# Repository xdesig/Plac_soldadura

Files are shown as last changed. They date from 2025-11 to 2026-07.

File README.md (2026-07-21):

#  Plataforma de Soldadura (Control de Temperatura)

> [!NOTE]
> Documentation in Galego 
> [traductor](https://tradutorgaio.xunta.gal/TradutorPublico/traducir/index)

Este repositorio conten o deseno de hardware, esquema e firmware para o desenvolvemento dun **controlador termico intelixente** aplicado a unha placa calefactora de 230Vac. O sistema esta desenado para labores de soldadura e desoldadura de componentes SMD/THD en proxectos persoais, educativos e experimentais.

---

## Versions do Proxecto

O repositorio esta dividido en duas variantes segundo o microcontrolador utilizado:

### 1. [Plataforma_sold_ATmega328p](./Plataforma_sold_ATmega328p)
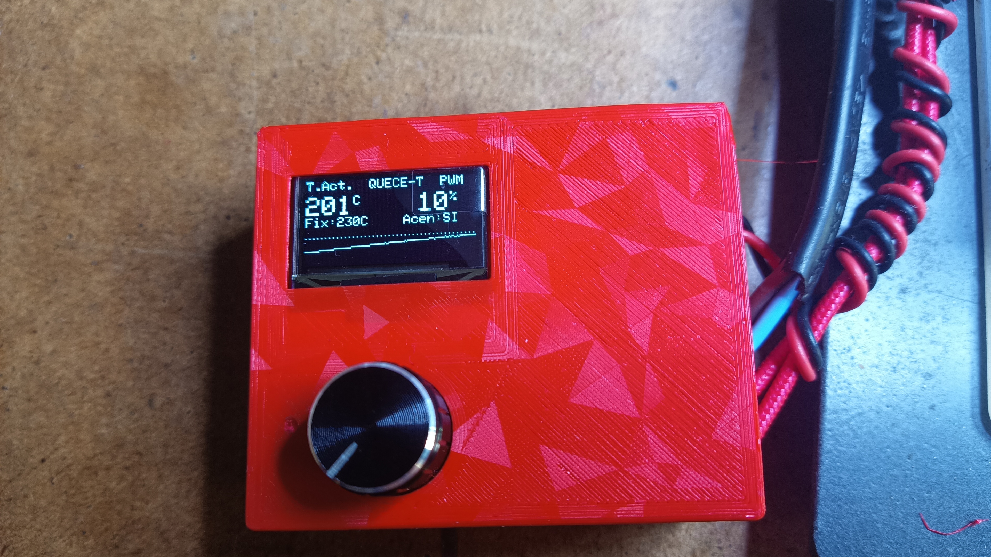
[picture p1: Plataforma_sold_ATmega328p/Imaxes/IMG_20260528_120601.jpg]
ATmega328P Version


- **Microcontrolador:** ATmega328P-AU (TQFP-32).
- **Descricion:** Version mais lixeira e eficiente baseada na arquitectura clasica de Arduino. Demostra que non e preciso usar un potente ESP32 para realizar este traballo.
**Caracteristicas:** Control de potencia, visualizacion en pantalla OLED 128x64 (SSD1306) e illamento galvanico.

**[Ver documentacion e BOM do ATmega328P](./Plataforma_sold_ATmega328p)**

---

### 2. [Plataforma_sold_ESP32-C3](./Plataforma_sold_ESP32-C3)
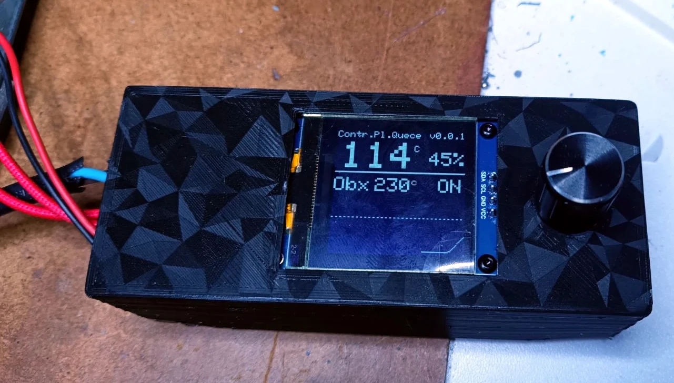
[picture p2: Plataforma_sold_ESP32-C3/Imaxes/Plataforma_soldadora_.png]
ESP32-C3 Version


**Microcontrolador:** ESP32-C3 SuperMini (RISC-V).
**Descricion:** Version baseada no chip ESP32-C3, aproveitando a sua maior velocidade de procesamento e conectividade.
**Caracteristicas:** Interface OLED I2C, control mediante encoder rotatorio e procesamento mais rapido da curva de temperatura.

**[Ver documentacion e BOM do ESP32-C3](./Plataforma_sold_ESP32-C3)**

---

##  Caracteristicas Xerais

Ambas versions comparten a seguinte arquitectura e funcionalidade basica:

- **Control Termico:** Axuste preciso da temperatura e control de potencia do elemento calefactor.
- **Seguridade:** Deteccion de fallos no termistor e corte de emerxencia por sobrequecemento (300 C).
- **Aisllamento:** Illamento galvanico mediante micro-fonte de alimentacion conmutada integrada na PCB.
- **Etapa de Potencia:** Control de carga AC a 230Vac mediante SSR / Triac (BTA06-400B e optoacoplador MOC3041).
- **Interface:** Pantalla OLED SSD1306 (128x64 px) e selector mediante encoder rotatorio e pulsador.

---

## Estrutura do Repositorio

* `Plataforma_sold_ATmega328p/`: Proxecto, PCB e BOM para ATmega328P
* `Plataforma_sold_ESP32-C3/`: Proxecto, PCB e BOM para ESP32-C3
* `README.md`: Descricion xeral do repositorio

---

Saúdos.

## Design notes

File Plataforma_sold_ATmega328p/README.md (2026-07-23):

# Controlador de placa para soldar Con ATmega328p


> [!NOTE]
> Documentation in Galego 
> [traductor](https://tradutorgaio.xunta.gal/TradutorPublico/traducir/index)

Tr&aacute;tase dun **controlador t&eacute;rmico intelixente** de placa calefactora 230Vac para soldar/desoldar, dese&ntilde;ado para uso persoal, educativo e experimental. Baseado en ATmega328, non &eacute; preciso usar un potente ESP32 para realizar este traballo, e permite:

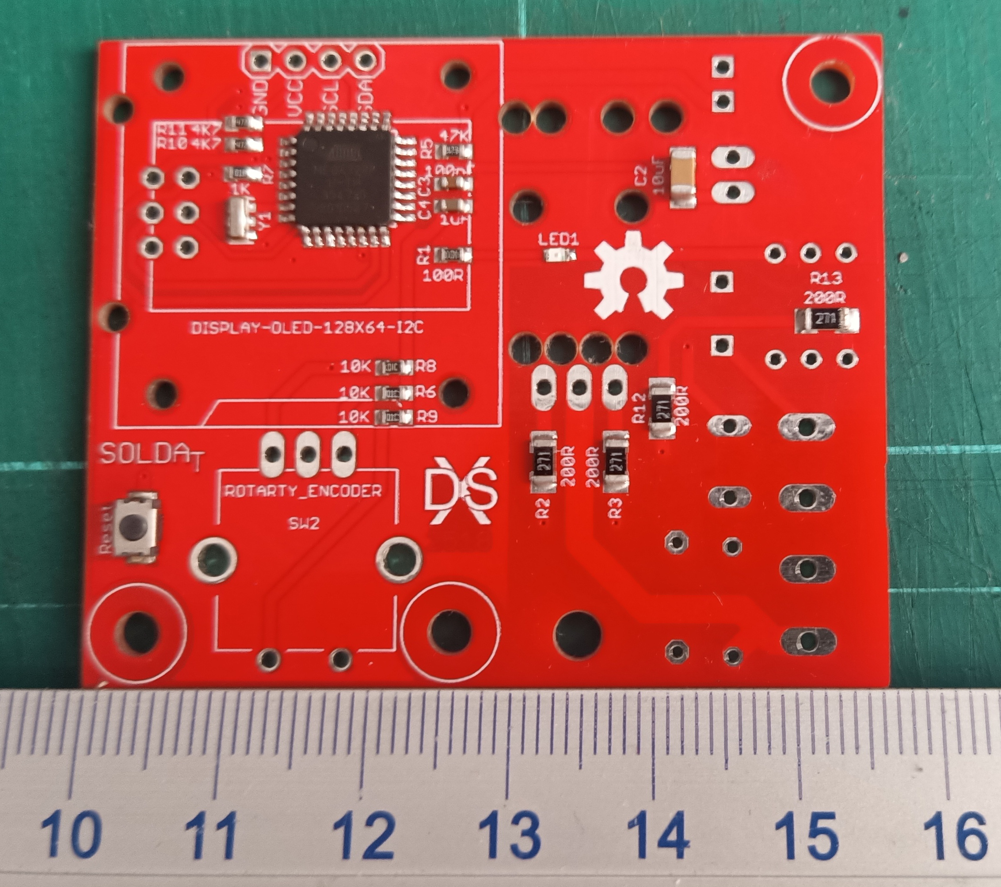
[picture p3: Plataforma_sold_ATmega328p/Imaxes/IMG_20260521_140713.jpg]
 
 
- Axuste preciso da temperatura (ata 300&deg;C).
- Control "PID" simple e estable.
- Detecci&oacute;n de fallos do termistor.
- Gr&aacute;fico en tempo real da temperatura.
- Indicador ON/OFF e potencia aplicada ao calefactor na pantalla.
- Corte de emerxencia por sobrequecemento (300&deg;C).
- Illamento galv&aacute;nico (micro-fonte de alimentaci&oacute;n conmutada).
- Control mediante SSR (Triac) a 230Vac.

<br>
---

## [Versi&oacute;n 00]

## Listado de Compoñentes (BOM)

|Cant | Valor | Dispositivo | Parte | Descrición |
|-----|---|---|---|---|
| **1** | 100R | R0603 | `R1` | Resistor |
| **1** | 100nF | C0603 | `C3` | Capacitor |
| **3** | 10K | R0603 | `R6`, `R8`, `R9` | Resistor |
| **1** | 10nF / 400V | C075-042X103 | `C1` | Capacitor (400V) |
| **1** | 10uF | C1206 | `C2` | Capacitor |
| **1** | 1K | R0603 | `R7` | Resistor |
| **1** | 1uF | C0603 | `C4` | Capacitor |
| **4** | 200R | R1206 | `R2`, `R3`, `R12`, `R13` | Resistor |
| **1** | 22-05-7028-02 | 7395-02 | `J1` | Connector |
| **1** | 39R | 0204/7 | `R4` | Resistor |
| **1** | 47K | R0603 | `R5` | Resistor |
| **2** | 4K7 | R0603 | `R10`, `R11` | Resistor |
| **1** | ATMEGA328P-AU | TQFP-32 | `IC3` | 8-bit Microcontrolador 32KB Flash |
| **1** | B3U-1000P | SMD_157SW | `S6` | Pulsador 4x3mm SMD H2.5mm |
| **1** | BTA06-400B (BT136) | TO-220AB | `T1` | Triac  |
| **1** | CSTCE16M0V53C-R0 | Resonador | `Y1` | Resonador 16MHz SMD |
| **1** | OLED 0.96" I2C | 128x64 Modulo | `OL1` | SSD1306 [GND, VCC, SCL, SDA] |
| **1** | Fusible| TE5 | `F1` | Fusible |
| **1** | MOC3041 | DIL06 / DIP-6 | `OK1` | Optoacoplador, Triac |
| **1** | Rotary Encoder | Rotary Enc Plain | `SW2` | Encoder rotativo pulsador |
| **1** | RPDZN5W6H | Module | `U1` | Modulo Micro fuente A. |

## Deseñado en Entrimo con agarimo.

### Author and license
* Author: XDeSIG [No Twitter, no X]
* License:[ CERN Open Hardware Licence Version 2 - S - Reciprocal][CERN-OHL-W]
* Certification:[ Open Hardware Certification: ES000057][OSHWA]

<br>

<p align="left">
  OSHW Facts
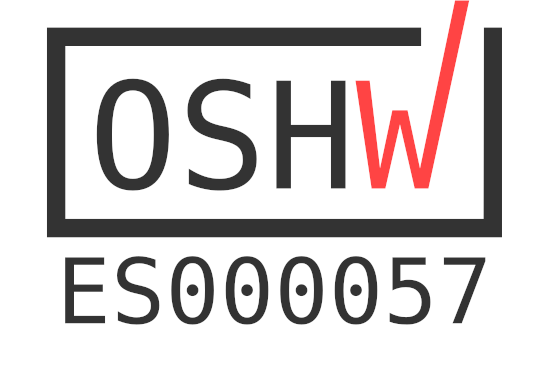
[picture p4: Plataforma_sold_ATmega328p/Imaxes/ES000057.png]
OSHWA Certification
  
</p>

Sa&uacute;dos.
---
[ROTARTY_ENCODER]: https://github.com/xdesig/Plac_soldadura/blob/main/Imaxes/Rotary_encoder.webp
[RPDZN5W6H]: https://github.com/xdesig/Plac_soldadura/blob/main/Imaxes/ac-dc_5V700mA.png
[CERN-OHL-W]: https://ohwr.org/cern_ohl_w_v2.pdf
[OSHWA]: https://certification.oshwa.org/list.html

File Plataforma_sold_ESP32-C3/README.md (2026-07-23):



> [!NOTE]
> Documentation in Galego 
> [traductor](https://tradutorgaio.xunta.gal/TradutorPublico/traducir/index)

Tr&aacute;tase dun **controlador t&eacute;rmico intelixente** de placa calefactora 230Vac para soldar/desoldar, dese&ntilde;ado para uso persoal, educativo e experimental. Esta versi&oacute;n est&aacute; basada no microcontrolador **ESP32-C3 SuperMini**, aproveitando a s&uacute;a alta velocidade e conectividade para a xesti&oacute;n de temperatura e control de potencia.

### Caracter&iacute;sticas principais:
- Axuste preciso da temperatura.
- Control de potencia e ciclo de quecemento.
- Detecci&oacute;n de fallos do sensor de temperatura.
- Visualizaci&oacute;n en pantalla OLED (SSD1306 / I2C).
- Corte de emerxencia por sobrequecemento.
- Illamento galv&aacute;nico (micro-fonte de alimentaci&oacute;n conmutada).
- Control de carga AC mediante triac / SSR.

---

## Listado de Compoñentes (BOM)

| Qty | Value | Device | Package | Parts | Description |
|-----|---|---|---|---|---|
| 1 | | AK500/4-H | AK500/4-H | `X1` | CONNECTOR |
| 1 | | LED3MM | LED3MM | `LED1` | LED 3mm RED |
| 3 | 10K | R-EU_R0603 | R0603 | `R6, R7, R8` | RESISTOR |
| 1 | 10R | R-EU_R0603 | R0603 |`R1` | RESISTOR |
| 1 | 10nF/400V | C-EU075-042X103 | C075-042X103 | `C1` | CAPACITOR |
| 1 | 10uF | C-EUC1206K | C1206K |`C2` | CAPACITOR |
| 1 | 22-27-2021-02| 22-27-2021-02 | 6410-02 | `J1` | CONNECTOR Molex |
| 2 | 390R | R-EU_0204/7 | 0204/7 | `R2, R3` | RESISTOR |
| 1 | 39R | R-EU_0204/7 | 0204/7 | `R4` | RESISTOR |
| 1 | 47K | R-EU_R0603 | R0603 | `R5` | RESISTOR |
| 1 | BTA06400B | BTA06400B | TO220AB | `T1` | Triac BTA |
| 1 | | DISPLAY-OLED-128X128-I2C | DISPLAY-OLED-1,5 pulgadas | `OLED` |SDA, SCL, GND, VCC  |
| 1 | | ESP32-C3_SUPERMINISMD | [ESP32 C3 Supermini]: | `U5` | |
| 1 | | FUS 5A | 8,5x4 | `F1` | Fuse 5A |
| 1 | | MOC3041 | IL410 | `OK1` | OPTO COUPLER |
| 1 | | ROTARTY_ENCODER | [ROTARTY_ENCODER] | `SW2` | Rotary encoder |
| 1 | | RPDZN5W6H | [RPDZN5W6H] | `U1` | AC-DC 5V 700mA |

## Deseñado en Entrimo con agarimo.

### Author and license
* Author: XDeSIG [No Twitter, no X]
* License:[ CERN Open Hardware Licence Version 2 - S - Reciprocal][CERN-OHL-W]
* Certification:[ Open Hardware Certification: ES000055][OSHWA]

<br>

<p align="left">
  OSHW Facts
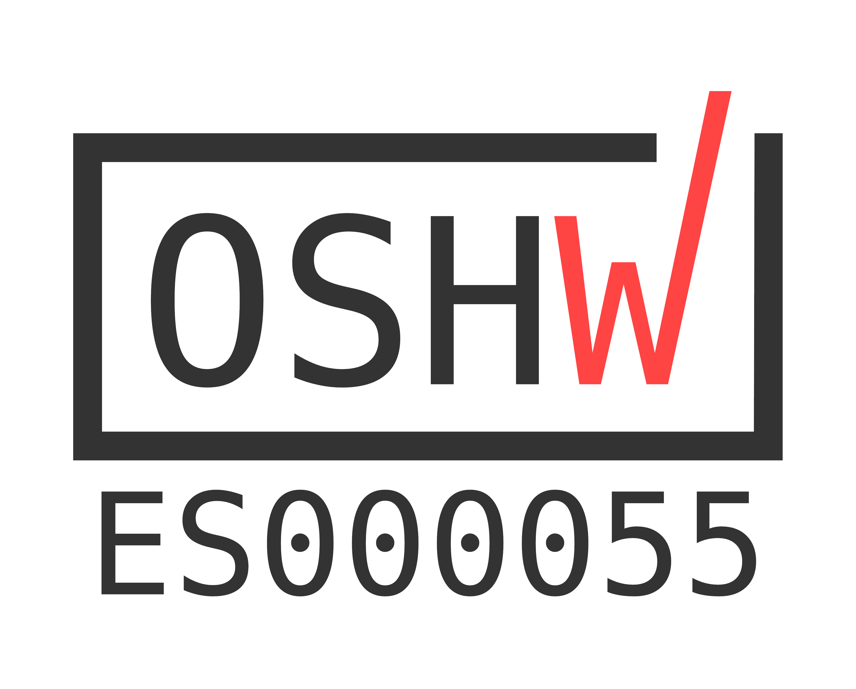
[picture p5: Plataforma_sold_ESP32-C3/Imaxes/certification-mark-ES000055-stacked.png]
OSHWA Certification
  
</p>

---

[ROTARTY_ENCODER]: https://github.com/xdesig/Plac_soldadura/blob/main/Imaxes/Rotary_encoder.webp
[ESP32 C3 Supermini]: https://github.com/xdesig/Plac_soldadura/blob/main/Imaxes/ESP32-C3.webp
[RPDZN5W6H]: https://github.com/xdesig/Plac_soldadura/blob/main/Imaxes/ac-dc_5V700mA.png
[CERN-OHL-W]: https://ohwr.org/cern_ohl_w_v2.pdf
[OSHWA]: https://certification.oshwa.org/list.html

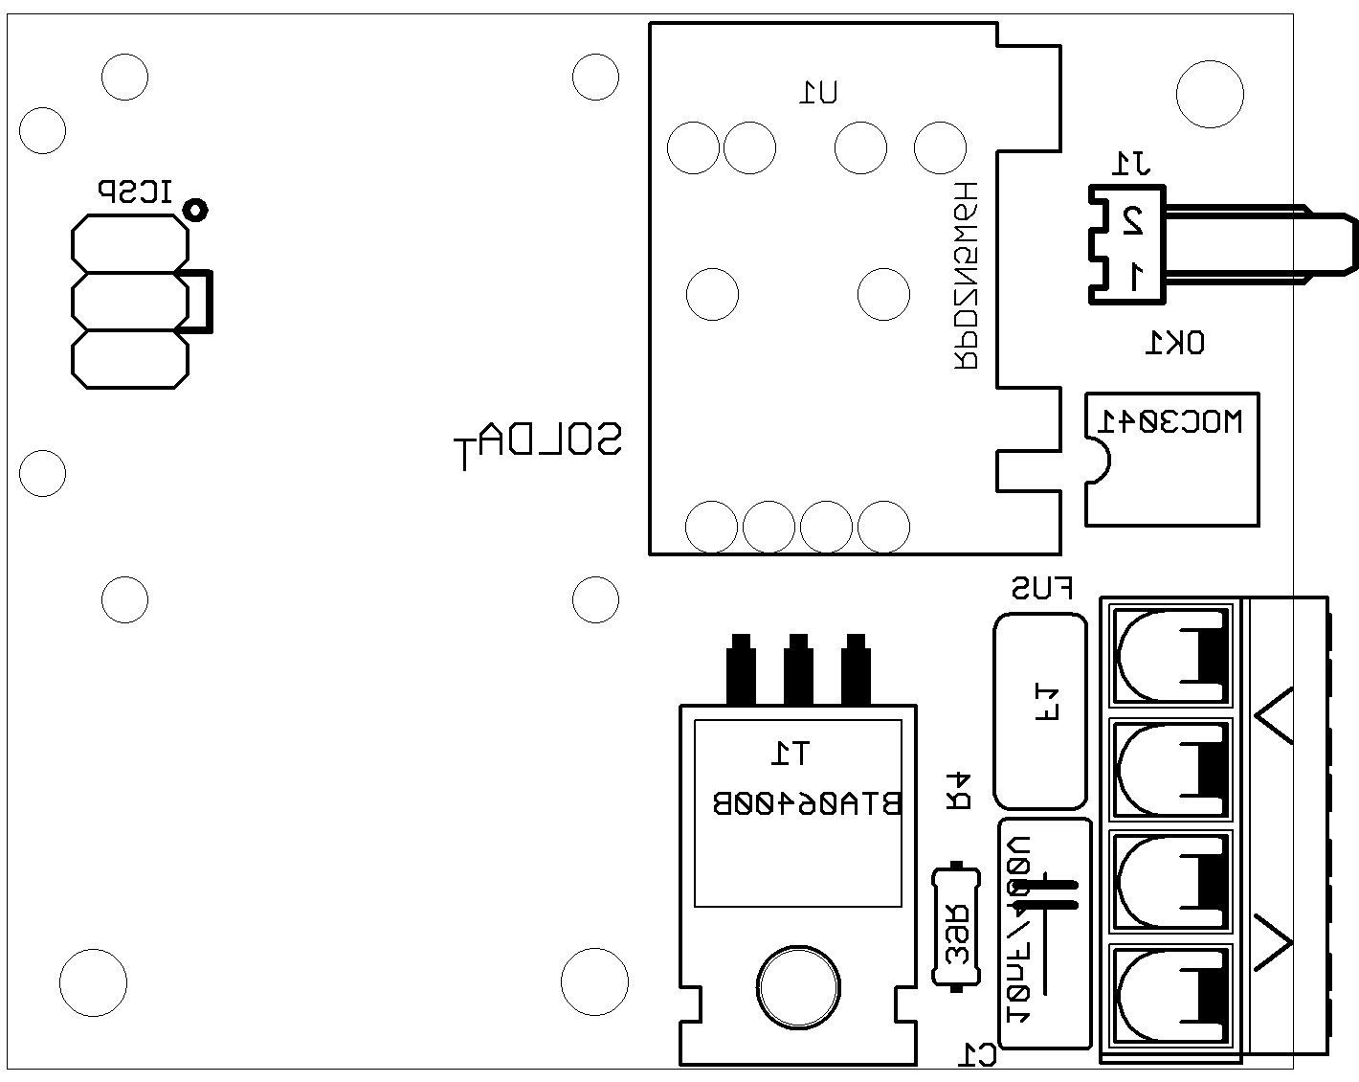
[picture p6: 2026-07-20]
Plataforma_sold_ATmega328p/Electronica/Plato_soldadura_328P_SilkBot.png

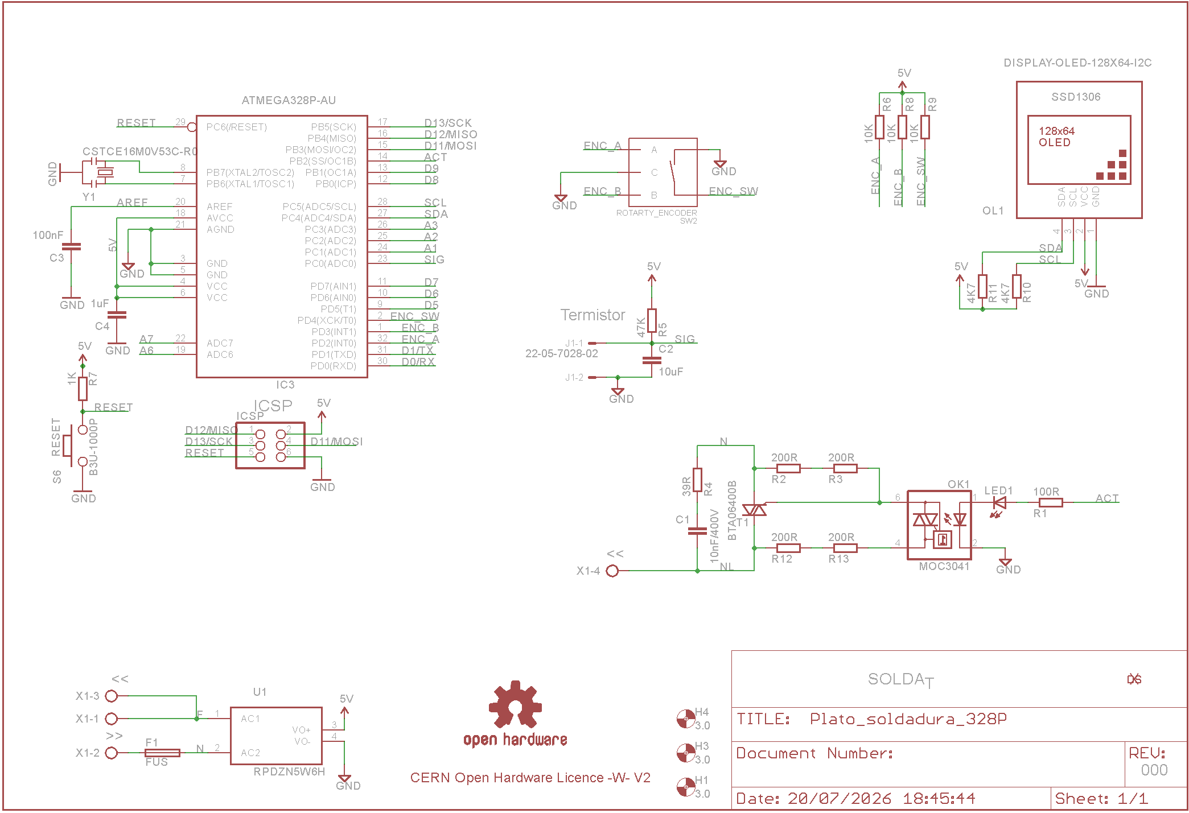
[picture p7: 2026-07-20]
Plataforma_sold_ATmega328p/Electronica/Plato_soldadura_328P_ESQ.png

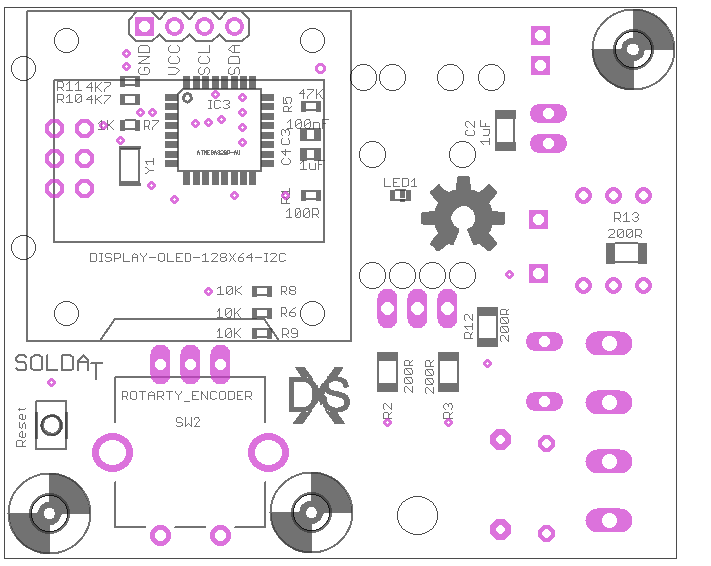
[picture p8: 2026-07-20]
Plataforma_sold_ATmega328p/Electronica/Plato_soldadura_328P_PlacTop.png

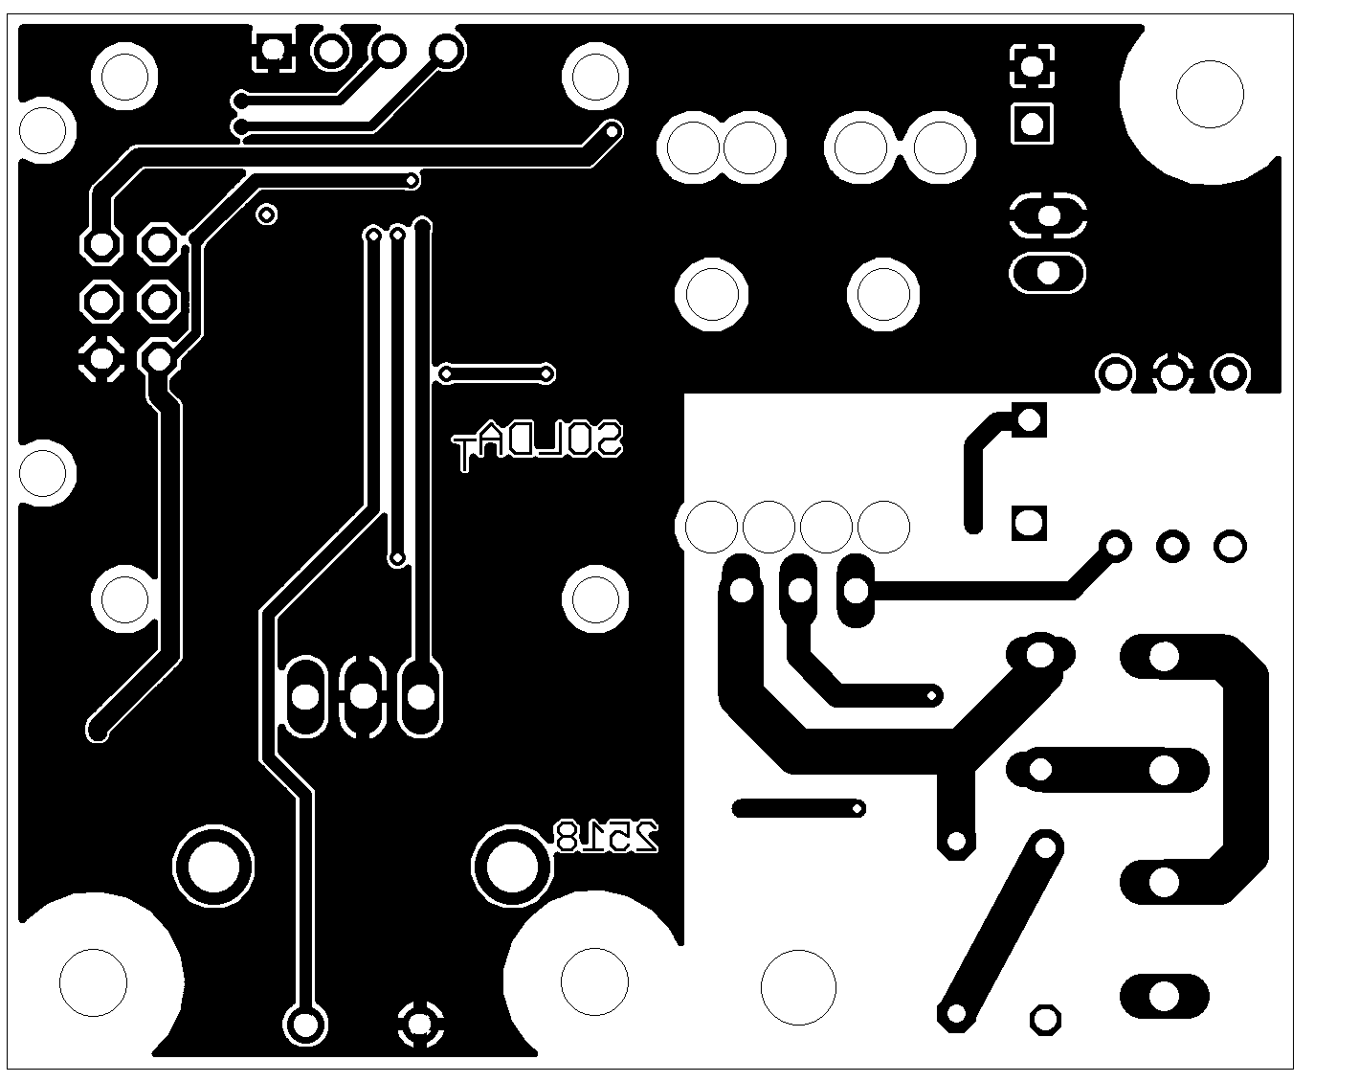
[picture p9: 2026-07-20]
Plataforma_sold_ATmega328p/Electronica/Plato_soldadura_328P_BOT.png

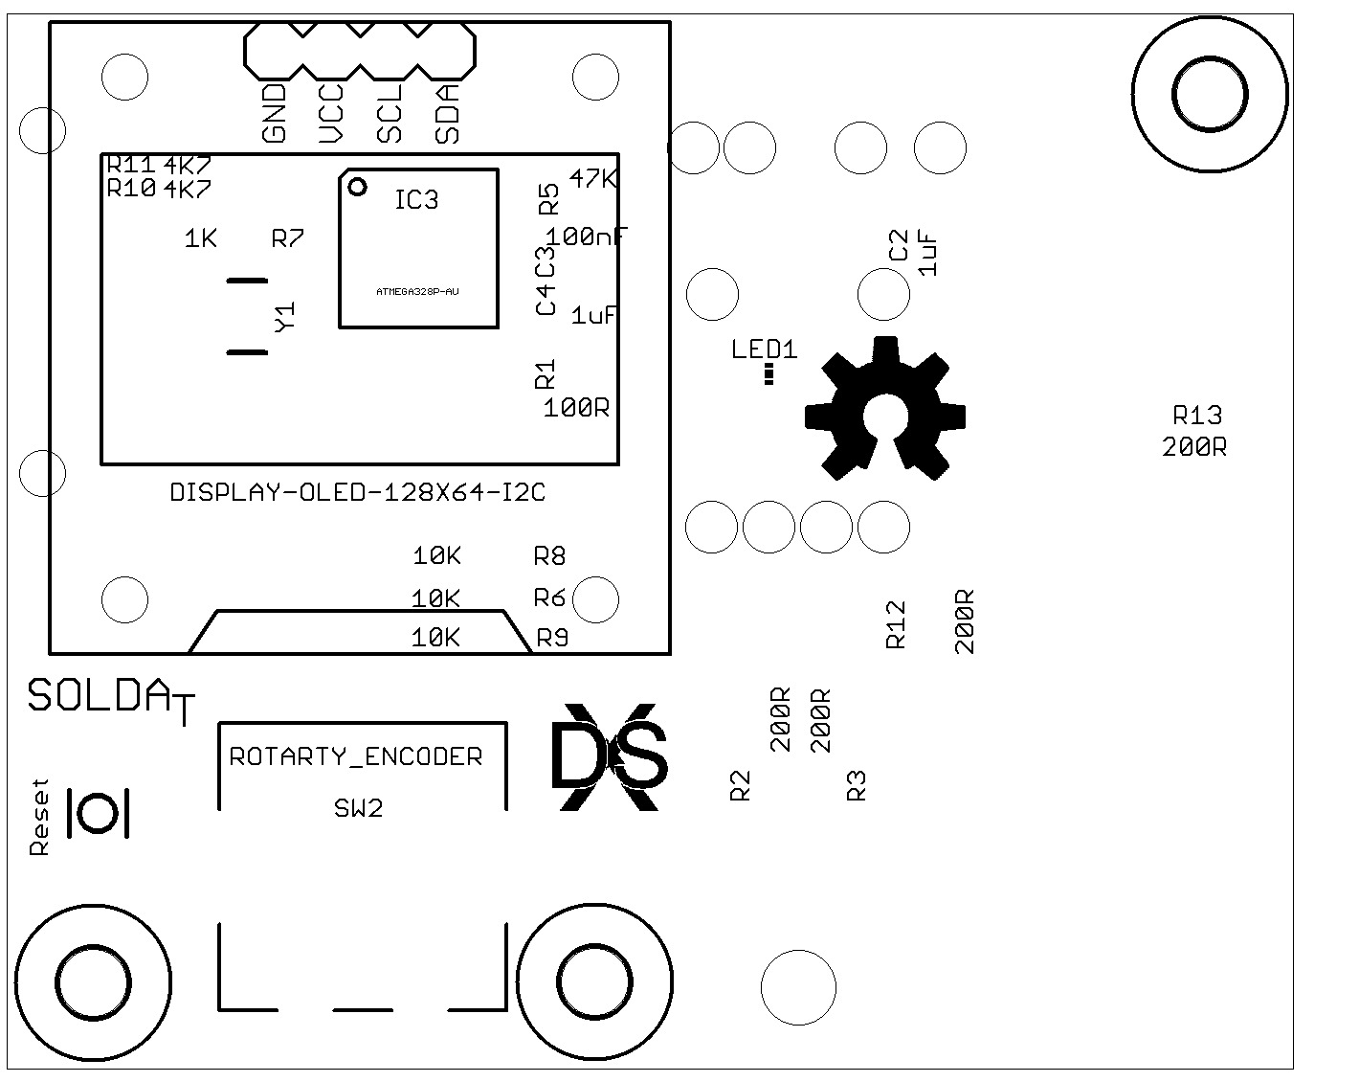
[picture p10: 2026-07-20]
Plataforma_sold_ATmega328p/Electronica/Plato_soldadura_328P_SilkTop.png

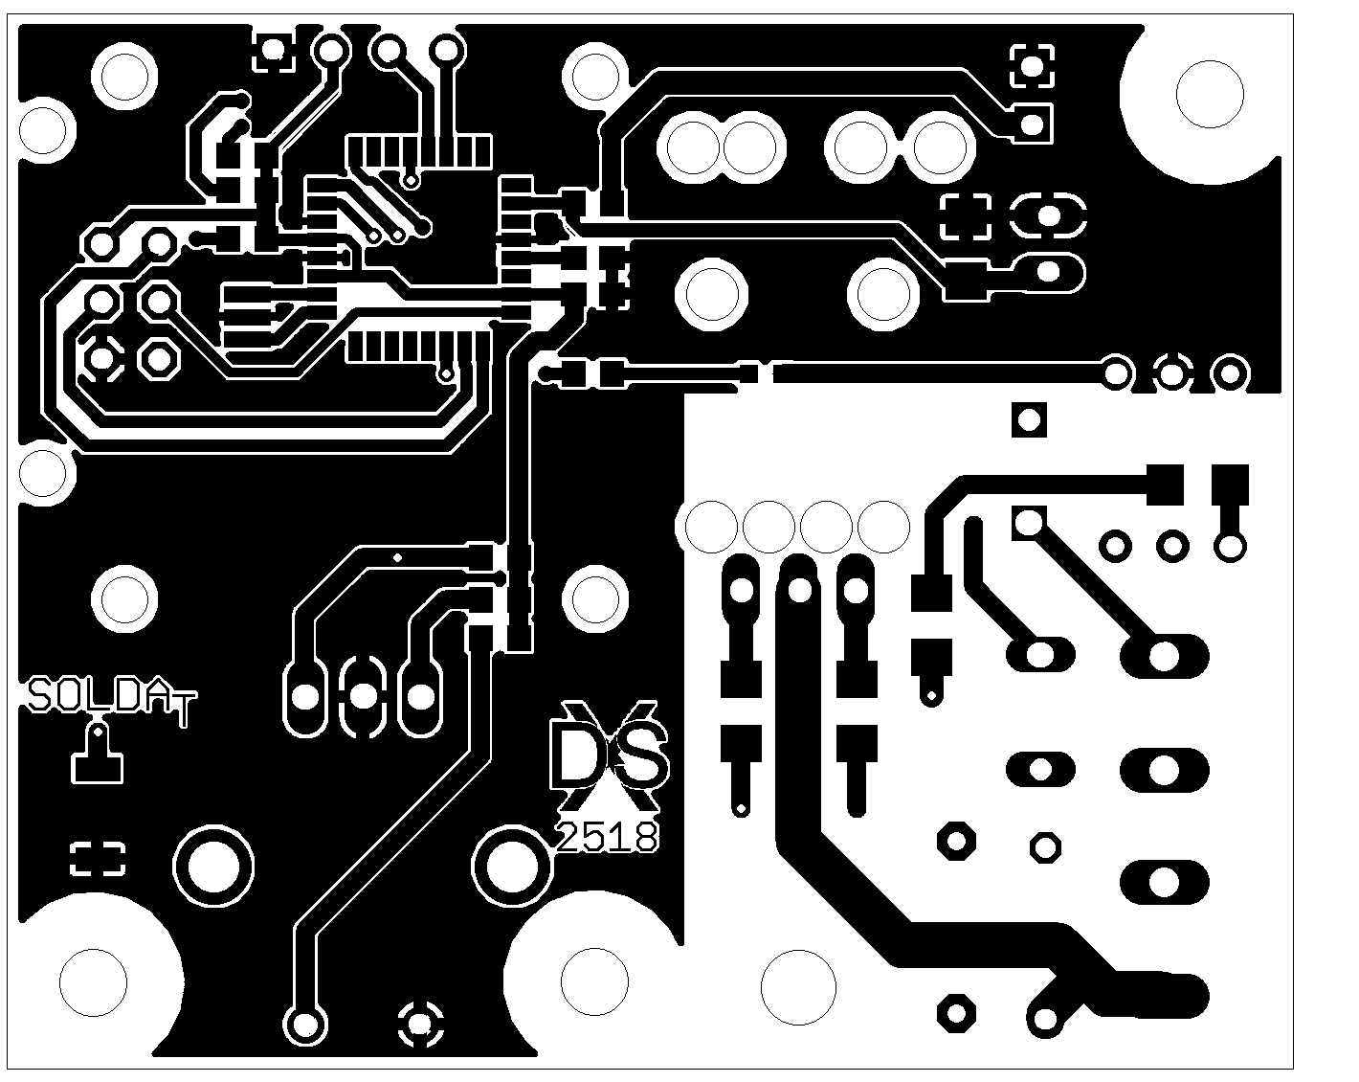
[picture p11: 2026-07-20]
Plataforma_sold_ATmega328p/Electronica/Plato_soldadura_328P_TOP.png

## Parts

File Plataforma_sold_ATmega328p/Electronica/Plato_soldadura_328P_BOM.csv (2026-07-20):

Qty | Value | Device | Package | Parts | Description | CASE | MF | MONTHLY_USAGE | MPN | OC_FARNELL | OC_NEWARK | PART_NUMBER | PRICE | SUPPLIER | TYPE | VALUE
1 |  | 0114_PH254-203DF118A00V | 2X03 | ICSP | 3x2 M V h 8,5 mm p2,54 |  |  | _____ |  |  |  | PH254-203DF118A00V | _____ | _____ | Connettori | ICSP
1 |  | AK500/4-H | AK500/4-H | X1 | CONNECTOR |  |  |  |  | unknown | unknown
1 |  | LEDCHIP-LED0603 | CHIP-LED0603 | LED1 | LED
1 | 100R | R-EU_R0603 | R0603 | R1 | RESISTOR, European symbol
1 | 100nF | C-EUC0603 | C0603 | C3 | CAPACITOR, European symbol
3 | 10K | R-EU_R0603 | R0603 | R6, R8, R9 | RESISTOR, European symbol
1 | 10nF/400V | C-EU075-042X103 | C075-042X103 | C1 | CAPACITOR, European symbol
1 | 10uF | C-EUC1206 | C1206 | C2 | CAPACITOR, European symbol
1 | 1K | R-EU_R0603 | R0603 | R7 | RESISTOR, European symbol
1 | 1uF | C-EUC0603 | C0603 | C4 | CAPACITOR, European symbol
4 | 200R | R-EU_R1206 | R1206 | R2, R3, R12, R13 | RESISTOR, European symbol
1 | 22-05-7028-02 | 22-05-7028-02 | 7395-02 | J1 | CONNECTOR |  |  |  |  | 9731601 | unknown
3 | 3.0 | MOUNT-HOLE3.0 | 3,0 | H1, H3, H4 | MOUNTING HOLE with drill center marker
1 | 39R | R-EU_0204/7 | 0204/7 | R4 | RESISTOR, European symbol
1 | 47K | R-EU_R0603 | R0603 | R5 | RESISTOR, European symbol
2 | 4K7 | R-EU_R0603 | R0603 | R10, R11 | RESISTOR, European symbol
1 | ATMEGA328P-AU | 0265_ATMEGA328P-AU | TQFP32-08 | IC3 | 8-bit Microcontroller with 32KBytes In-System Programmable Flash ATMEGA328P-AU | TQFP32_7x7 |  | _____ |  |  |  | ATMEGA328P-AU | _____ | _____ | Circuito_Integrato | ATMEGA328P-AU
1 | B3U-1000P | 0173_IT-1185AP1C-160G-G_T&R | SMD_157SW | S6 | Pushbutton 4x3 SMD H2,5mm |  |  | _____ |  |  |  | IT-1185AP1C-160G-G_T&R | _____ | _____ | Switches | 157SW
1 | BTA06400B | BT136 | TO220AB | T1 | Triac BT136 series E sensitive gate
1 | CSTCE16M0V53C-R0 | 0011_CSTCE16M0V53-R0 | RESONATOR | Y1 | 16Mhz - SMD |  |  | _____ |  |  |  | CSTCE16M0V53-R0 | _____ | _____ | Cristalli | CSTCE16M0V53-R0
1 | DISPLAY-OLED-128X64-I2C | DISPLAY-OLED-128X64-I2C | DISPLAY-OLED-128X64-I2C | OL1 | 128x64 Dot Matrix OLED Module based on SSD1306 chip
1 | FUS | FUSETE5 | TE5 | F1 | Fuse |  |  |  |  | unknown | unknown
1 | MOC3041 | IL410 | DIL06 | OK1 | SIEMENS OPTO COUPLER |  | VISHAY/TELEFUNKEN |  | IL410 | 1045434 | 58K1715
1 | OSHW-LOGOL | OSHW-LOGOL | ESCORNA_LBRESCORNA_CPU_2_10_SPARKFUN-AESTHETICS_OSHW-LOGO-L | LOGO2 | Open Source Hardware Logo This logo indicates the piece of hardware it is found on incorporates a OSHW license and/or adheres to the definition of open source hardware found here: http://freedomdefined.org/OSHW
1 | ROTARTY_ENCODER | ROTARTY_ENCODER | ROTARY_ENC_PLAIN | SW2 | Simple no LED rotary encoder
1 | RPDZN5W6H | RPDZN5W6H | RPDZN5W6H | U1
1 | XDESIG_XDESIG21 | XDESIG_XDESIG21 | XDESIG_XDESIG | U$8
1 | XDESIG_XDESIG5MM | XDESIG_XDESIG5MM | XDESIG_XDESIG_CU | U$7

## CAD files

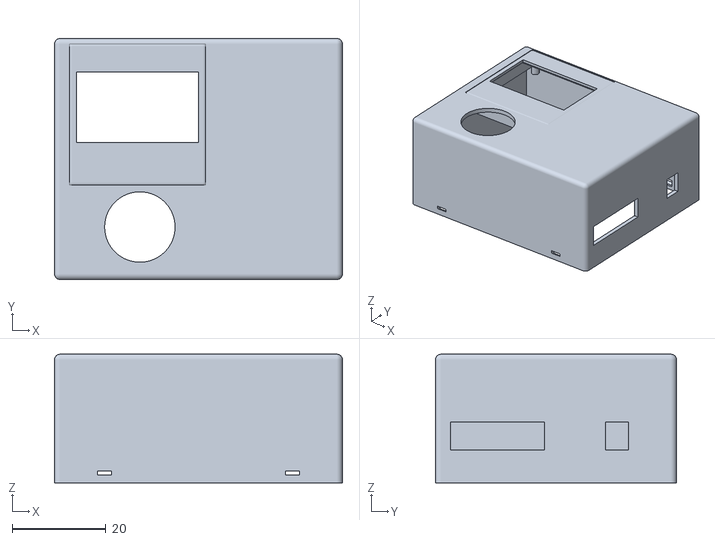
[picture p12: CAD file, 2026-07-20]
Plataforma_sold_ATmega328p/Caixa/Soldadura_328P_Caixa.stl
61.4 x 51.4 x 27.5

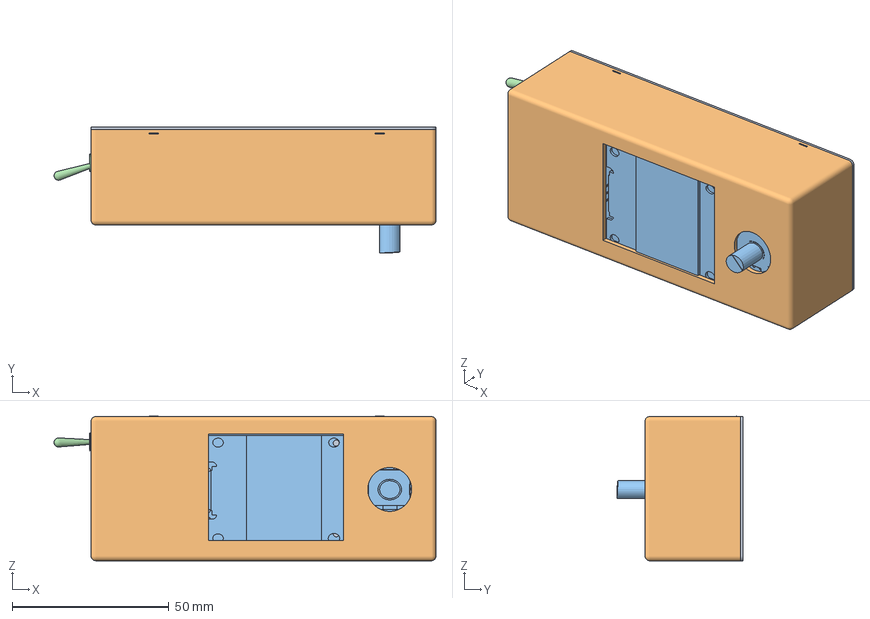
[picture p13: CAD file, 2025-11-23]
Plataforma_sold_ESP32-C3/Caixa/Plataforma_soldadora_caixa_1.FCStd
121.8 x 40.2 x 46.1 mm
Tapa
Caixa
Plataforma_soldadora
255SB

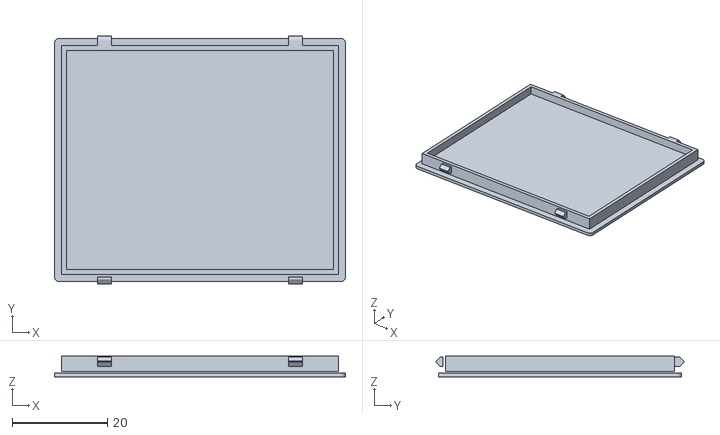
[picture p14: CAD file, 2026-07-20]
Plataforma_sold_ATmega328p/Caixa/Soldadura_328P_Tapa.stl
61.0 x 52.0 x 4.35

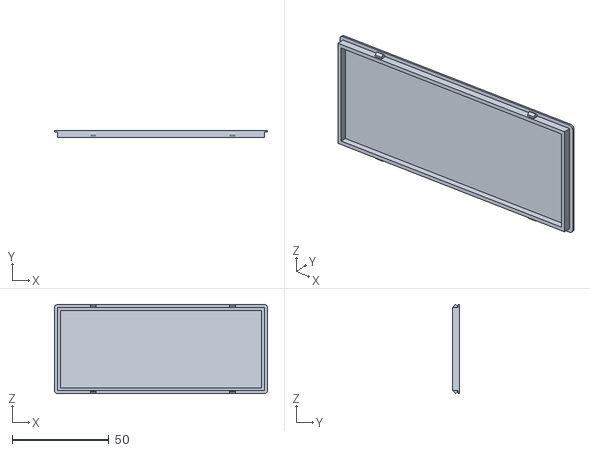
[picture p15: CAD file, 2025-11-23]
Plataforma_sold_ESP32-C3/Caixa/Plataforma_soldadora_tapa_1.stl
110.0 x 3.75 x 46.1

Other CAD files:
Plataforma_sold_ESP32-C3/Caixa/Plataforma_soldadora_caixa_1.stl

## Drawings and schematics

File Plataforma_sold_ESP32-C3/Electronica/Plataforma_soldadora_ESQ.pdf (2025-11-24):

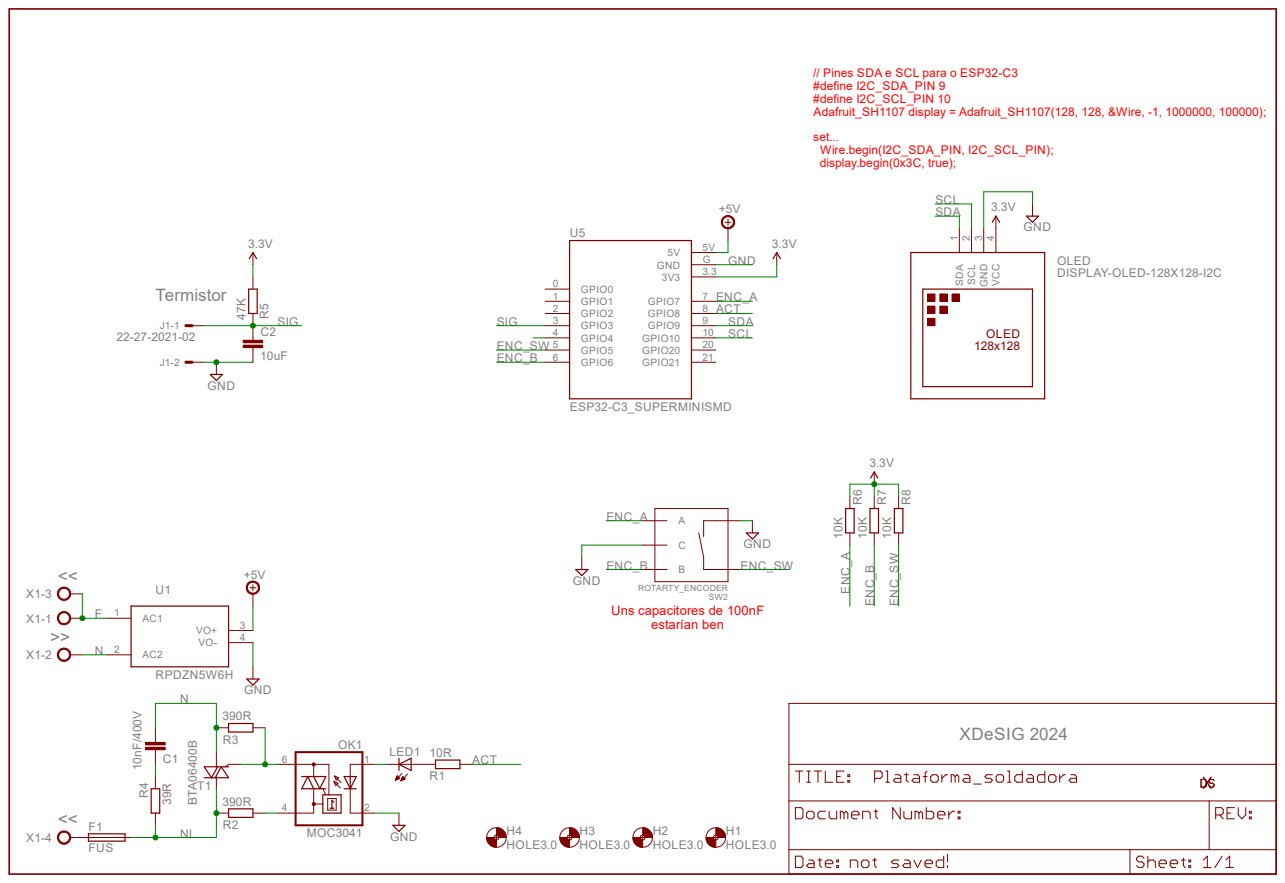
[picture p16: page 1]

// Pines SDA e SCL para o ESP32-C3
#define I2C_SDA_PIN 9
#define I2C_SCL_PIN 10
Adafruit_SH1107 display = Adafruit_SH1107(128, 128, &Wire, -1, 1000000, 100000);
set...
Wire.begin(I2C_SDA_PIN, I2C_SCL_PIN);
display.begin(0x3C, true);

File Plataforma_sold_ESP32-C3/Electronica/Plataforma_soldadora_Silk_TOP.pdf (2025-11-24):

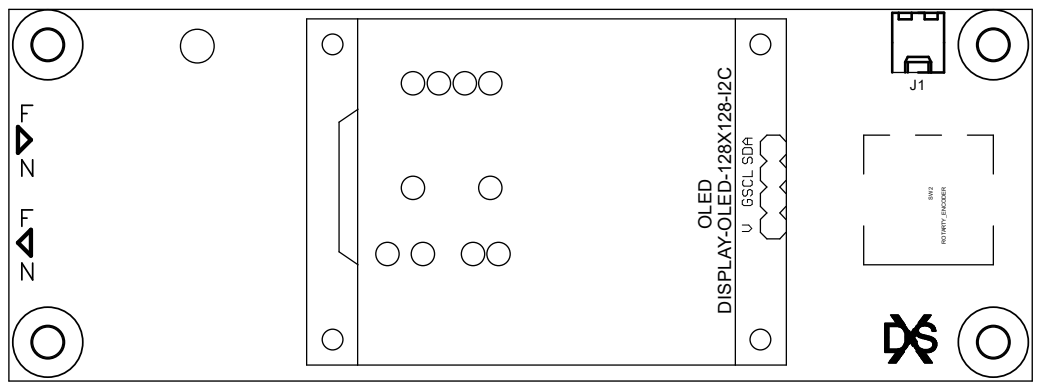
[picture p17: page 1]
SW2 OLED

J1 ROTARTY_ENCODER DISPLAY⁻OLED⁻¹²⁸X¹²⁸⁻I2C

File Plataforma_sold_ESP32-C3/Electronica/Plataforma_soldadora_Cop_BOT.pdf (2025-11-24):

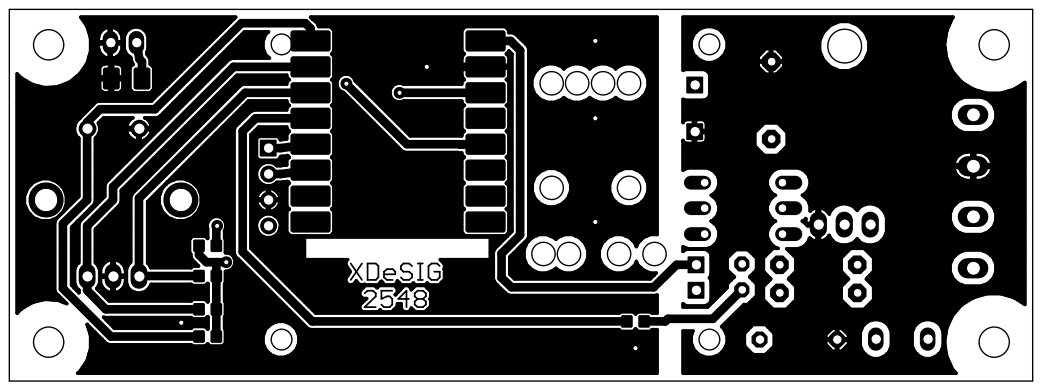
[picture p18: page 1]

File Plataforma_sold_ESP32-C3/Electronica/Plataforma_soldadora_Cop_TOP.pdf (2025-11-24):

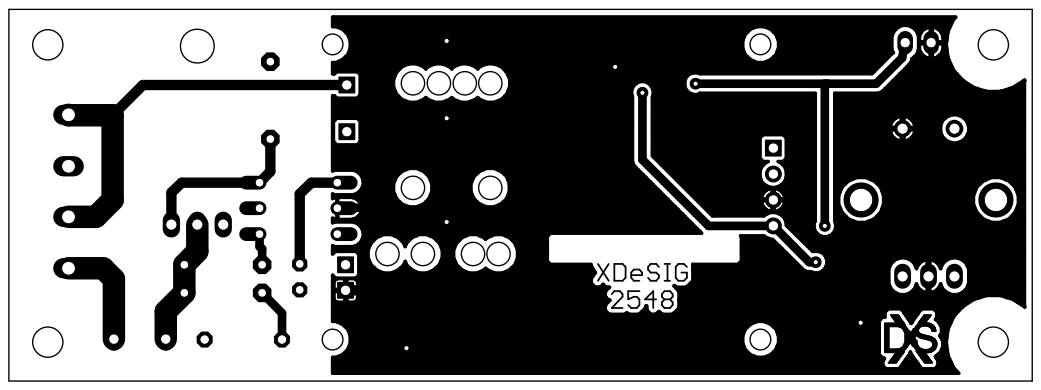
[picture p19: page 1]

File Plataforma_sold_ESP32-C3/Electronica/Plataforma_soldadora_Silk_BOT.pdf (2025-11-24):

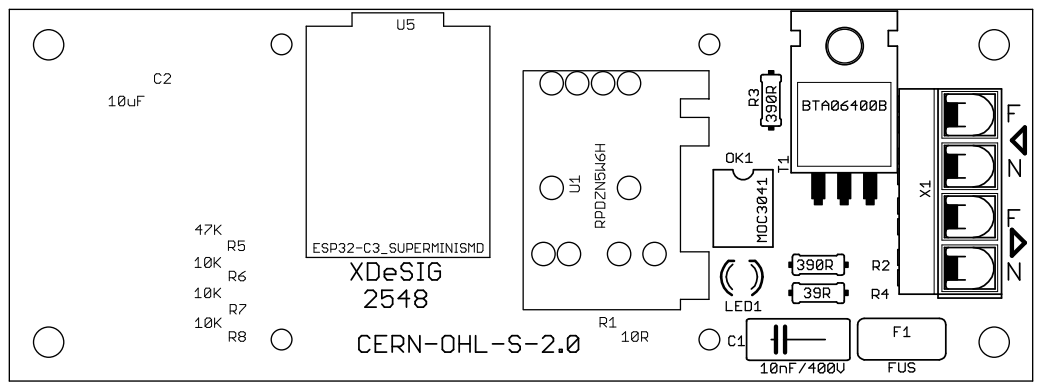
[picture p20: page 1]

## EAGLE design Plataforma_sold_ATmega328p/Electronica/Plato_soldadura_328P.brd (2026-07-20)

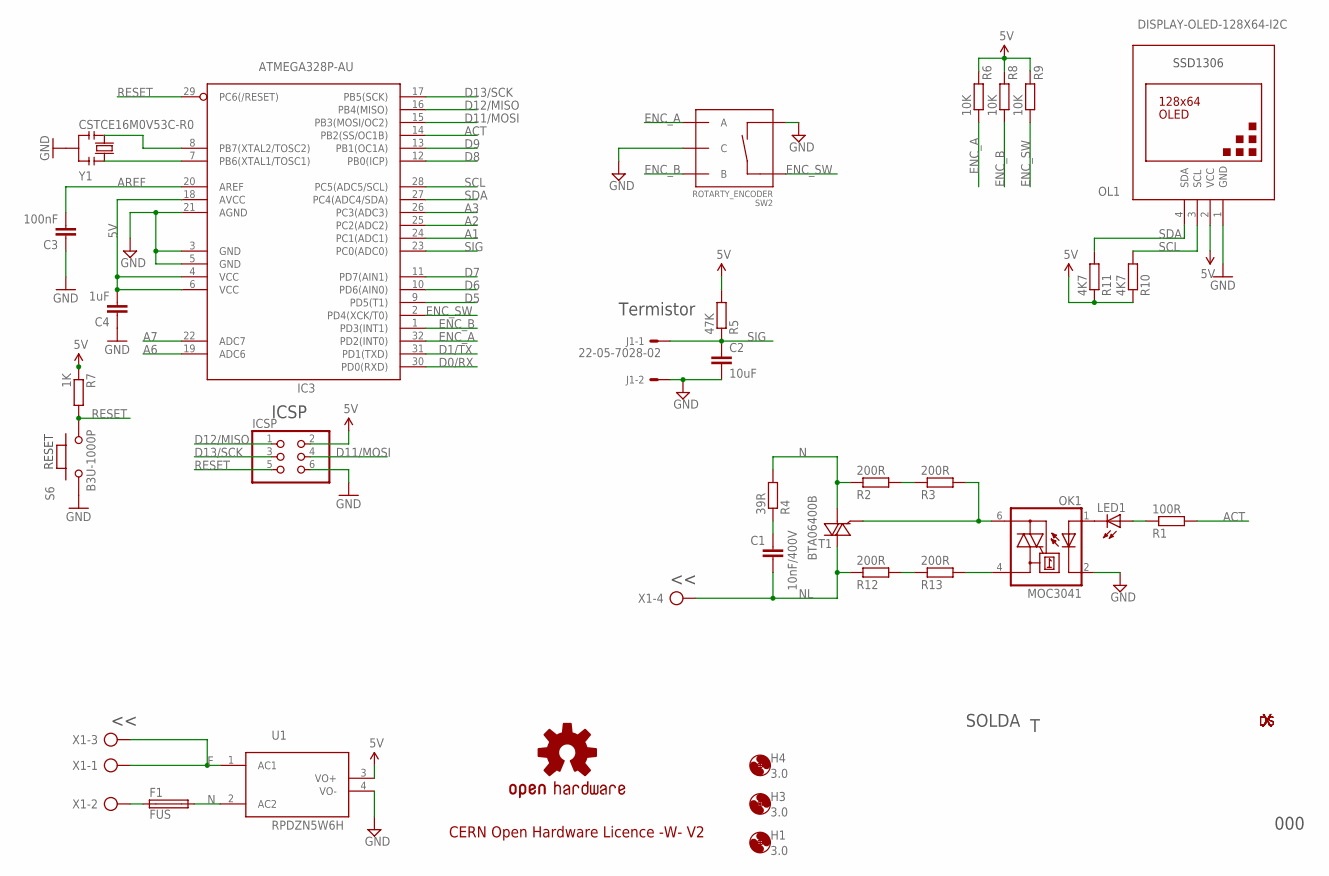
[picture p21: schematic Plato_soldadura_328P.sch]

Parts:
C1: 10nF/400V; C075-042X103
C2: 10uF; C1206
C3: 100nF; C0603
C4: 1uF; C0603
F1: FUS; TE5
H1, H3, H4: 3.0; 3,0
IC3: ATMEGA328P-AU; TQFP32-08
ICSP: 0114_PH254-203DF118A00V; 2X03
J1: 22-05-7028-02; 7395-02
LED1: LEDCHIP-LED0603; CHIP-LED0603
LOGO2: OSHW-LOGOL; ESCORNA_LBRESCORNA_CPU_2_10_SPARKFUN-AESTHETICS_OSHW-LOGO-L
OK1: MOC3041; DIL06
OL1: DISPLAY-OLED-128X64-I2C
R1: 100R; R0603
R2, R3, R12, R13: 200R; R1206
R4: 39R; 0204/7
R5: 47K; R0603
R6, R8, R9: 10K; R0603
R7: 1K; R0603
R10, R11: 4K7; R0603
S6: B3U-1000P; SMD_157SW
SW2: ROTARTY_ENCODER; ROTARY_ENC_PLAIN
T1: BTA06400B; TO220AB
U1: RPDZN5W6H
U$7: XDESIG_XDESIG5MM; XDESIG_XDESIG_CU
U$8: XDESIG_XDESIG21; XDESIG_XDESIG
X1: AK500/4-H
Y1: CSTCE16M0V53C-R0; RESONATOR

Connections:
5V: C4.2, IC3.4 (VCC), IC3.6 (VCC), IC3.18 (AVCC), ICSP.2, OL1.2 (VCC), R5.2, R6.2, R7.1, R8.2, R9.2, R10.1, R11.1, U1.3 (VO+)
A1: IC3.24 (PC1(ADC1))
A2: IC3.25 (PC2(ADC2))
A3: IC3.26 (PC3(ADC3))
A6: IC3.19 (ADC6)
A7: IC3.22 (ADC7)
ACT: IC3.14 (PB2(SS/OC1B)), R1.2
AREF: C3.2, IC3.20 (AREF)
D0/RX: IC3.30 (PD0(RXD))
D1/TX: IC3.31 (PD1(TXD))
D5: IC3.9 (PD5(T1))
D6: IC3.10 (PD6(AIN0))
D7: IC3.11 (PD7(AIN1))
D8: IC3.12 (PB0(ICP))
D9: IC3.13 (PB1(OC1A))
D11/MOSI: IC3.15 (PB3(MOSI/OC2)), ICSP.4
D12/MISO: IC3.16 (PB4(MISO)), ICSP.1
D13/SCK: IC3.17 (PB5(SCK)), ICSP.3
ENC_A: IC3.32 (PD2(INT0)), R6.1, SW2.A
ENC_B: IC3.1 (PD3(INT1)), R8.1, SW2.B
ENC_SW: IC3.2 (PD4(XCK/T0)), R9.1, SW2.SW+
F: U1.1 (AC1), X1.1, X1.3
GND: C2.2, C3.1, C4.1, IC3.3 (GND), IC3.5 (GND), IC3.21 (AGND), ICSP.6, J1.2, OK1.2 (C), OL1.1 (GND), S6.1, SW2.C, SW2.SW-, U1.4 (VO-), Y1.2
N: F1.2, R2.1, R4.2, T1.1 (A1), U1.2 (AC2)
unnamed: OK1.4 (A1), R13.2
unnamed: F1.1, X1.2
unnamed: OK1.6 (A2), R3.2, T1.3 (G)
unnamed: LED1.C, OK1.1 (A)
unnamed: LED1.A, R1.1
unnamed: R2.2, R3.1
unnamed: R12.2, R13.1
unnamed: C1.1, R4.1
unnamed: IC3.7 (PB6(XTAL1/TOSC1)), Y1.1
unnamed: IC3.8 (PB7(XTAL2/TOSC2)), Y1.3
NL: C1.2, R12.1, T1.2 (A2), X1.4
RESET: IC3.29 (PC6(/RESET)), ICSP.5, R7.2, S6.2
SCL: IC3.28 (PC5(ADC5/SCL)), OL1.3 (SCL), R10.2
SDA: IC3.27 (PC4(ADC4/SDA)), OL1.4 (SDA), R11.2
SIG: C2.1, IC3.23 (PC0(ADC0)), J1.1, R5.1

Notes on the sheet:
CERN Open Hardware Licence -W- V2
ICSP
RESET
Termistor
SOLDA
SSD1306
000

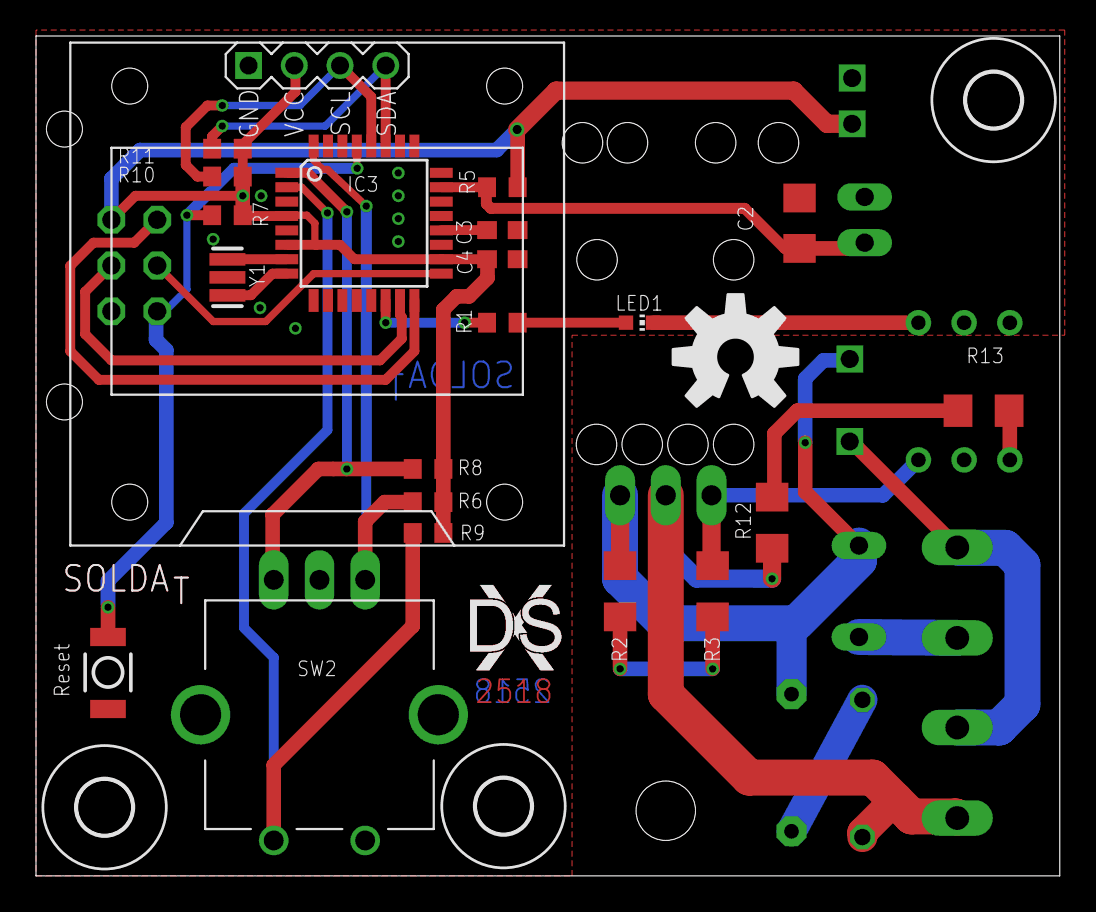
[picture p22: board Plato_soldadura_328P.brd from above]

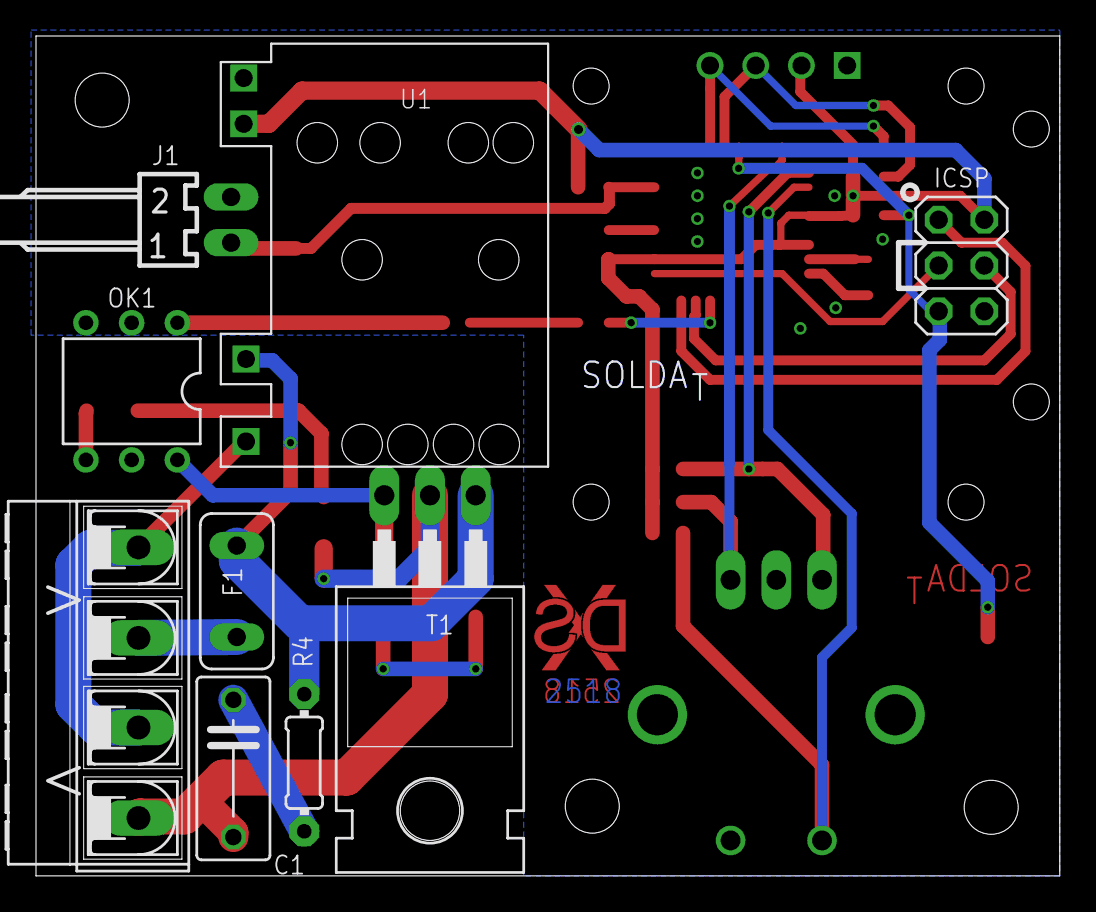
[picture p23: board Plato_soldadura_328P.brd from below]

Board: 2 copper layers, 56.9 x 46.7 mm, 36 parts (9 on the bottom side), 27 nets.

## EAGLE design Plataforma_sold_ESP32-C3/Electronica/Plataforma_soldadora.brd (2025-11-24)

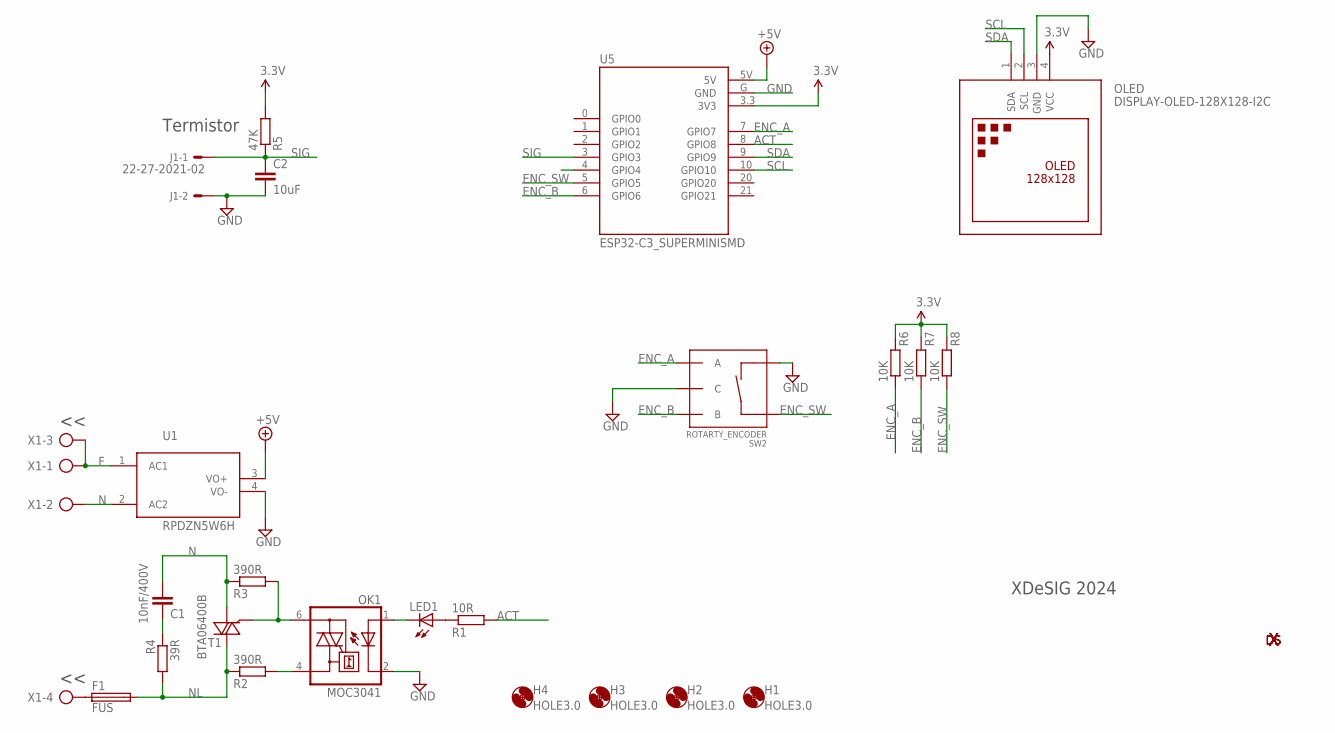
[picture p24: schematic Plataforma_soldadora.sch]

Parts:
C1: 10nF/400V; C075-042X103
C2: 10uF; C1206K
F1: FUS; TE5
H1, H2, H3, H4: HOLE3.0; HOLES_3,0
J1: 22-27-2021-02; 6410-02
LED1: LED3MM
OK1: MOC3041; DIL06
OLED: DISPLAY-OLED-128X128-I2C
R1: 10R; R0603
R2, R3: 390R; 0204/7
R4: 39R; 0204/7
R5: 47K; R0603
R6, R7, R8: 10K; R0603
SW2: ROTARTY_ENCODER; ROTARY_ENC_PLAIN
T1: BTA06400B; TO220AB
U1: RPDZN5W6H
U5: ESP32-C3_SUPERMINISMD; MODULE_ESP-C3_SUPERMINI_SMD
U$2: XDESIG_XDESIG5MM; XDESIG_XDESIG_CU
U$3: XDESIG_XDESIG21; XDESIG_XDESIG
X1: AK500/4-H

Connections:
3.3V: OLED.4 (VCC), R5.2, R6.2, R7.2, R8.2, U5.3.3 (3V3)
+5V: U1.3 (VO+), U5.5V
ACT: R1.2, U5.8 (GPIO8)
ENC_A: R6.1, SW2.A, U5.7 (GPIO7)
ENC_B: R7.1, SW2.B, U5.6 (GPIO6)
ENC_SW: R8.1, SW2.SW+, U5.5 (GPIO5)
F: U1.1 (AC1), X1.1, X1.3
GND: C2.2, J1.2, OK1.2 (C), OLED.3 (GND), SW2.C, SW2.SW-, U1.4 (VO-), U5.G (GND)
N: C1.2, R3.1, T1.1 (A1), U1.2 (AC2), X1.2
unnamed: OK1.4 (A1), R2.2
unnamed: F1.1, X1.4
unnamed: OK1.6 (A2), R3.2, T1.3 (G)
unnamed: LED1.K (C), OK1.1 (A)
unnamed: LED1.A, R1.1
unnamed: C1.1, R4.1
NL: F1.2, R2.1, R4.2, T1.2 (A2)
SCL: OLED.2 (SCL), U5.10 (GPIO10)
SDA: OLED.1 (SDA), U5.9 (GPIO9)
SIG: C2.1, J1.1, R5.1, U5.3 (GPIO3)

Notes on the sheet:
Termistor
XDeSIG 2024

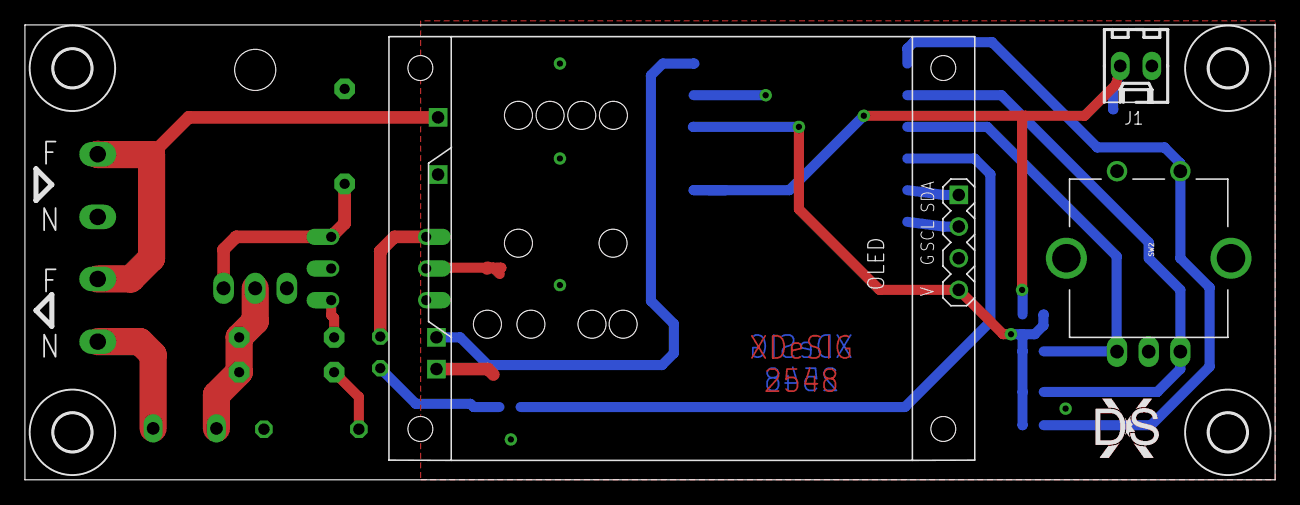
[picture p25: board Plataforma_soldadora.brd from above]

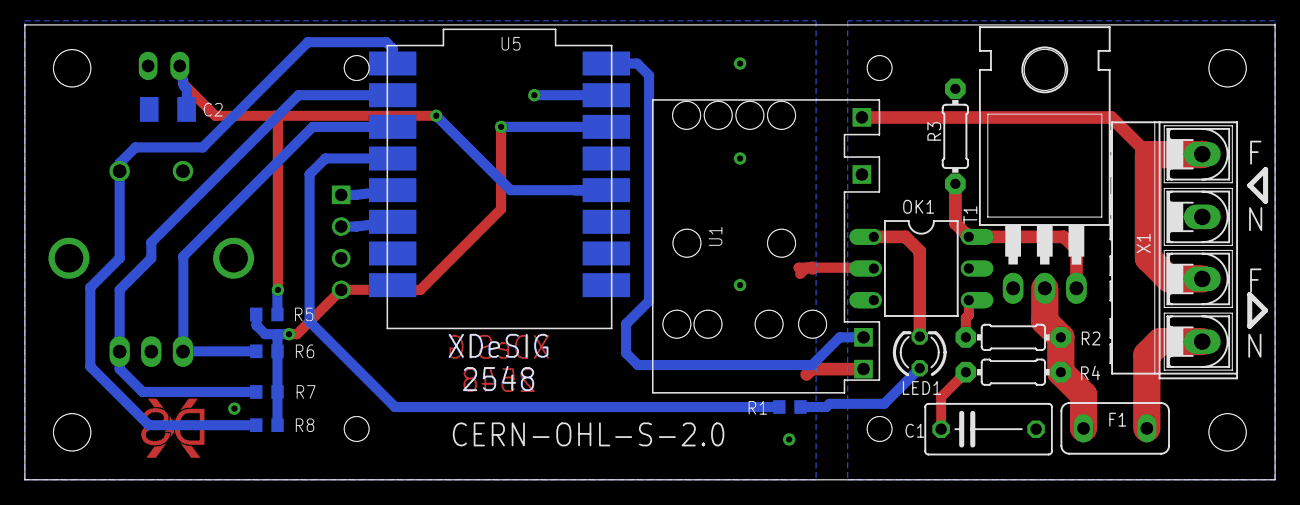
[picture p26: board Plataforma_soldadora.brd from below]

Board: 2 copper layers, 100.3 x 36.5 mm, 26 parts (17 on the bottom side), 19 nets.

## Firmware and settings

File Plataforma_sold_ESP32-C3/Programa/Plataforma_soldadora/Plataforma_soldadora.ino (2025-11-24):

/* CERN Open Hardware Licence -W- V2
 * =============================================================
 * PROXECTO: Controlador Intelixente de Placa Calefactora para soldar/desoldar
 * AUTOR: XDeSIG
 * LICENZA: Código fonte aberto (Open Source)
 * PLATAFORMA: ESP32-C3
 * PANTALLA: OLED SH1107 (128x128)
 * FUNCIONALIDADES:
 *   - Control térmico con termistor NTC 100kΩ
 *   - Axuste de temperatura mediante codificador rotativo
 *   - Controlador P simple estable e seguro
 *   - Gráfico en tempo real da temperatura
 *   - Detección de fallos do sensor (desconexión)
 *   - Corte de emerxencia por sobrecalentamento
 *   - Logo de XDeSIG ao arrancar
 *   - Indicador ON/OFF do calefactor na pantalla principal
 * 
 * Este software é de fonte libre e está deseñado para uso educativo,
 * experimental e persoal. Podes modificar, compartir e mellorar este
 * código libremente, sempre que se recoñeza a autoría orixinal.
 * CERN-OHL-W V2.0
 * 
 * Feito con agarimo en Estrimia
 * =============================================================
 */

#include <Arduino.h>
#include <Wire.h>
#include <Encoder.h>
#include <Adafruit_GFX.h>
#include <Adafruit_SH110X.h>
#include <math.h>

// =============================================================================
// VERSIÓN DO SOFTWARE
// =============================================================================
const char* VERSIÓN_SOFTWARE = "v0.0.1";  // Versión inicial

// =============================================================================
// CONFIGURACIÓN AXUSTABLE POLO USUARIO
// =============================================================================
#define TEMP_MINIMA 20           // Temperatura mínima permitida (°C)
#define TEMP_MAXIMA 300          // Temperatura máxima permitida (°C)
#define PWM_MAX_SAIDA 230        // Potencia máxima do calefactor (0-255)
#define CORTE_EMERXENCIA 301.0f  // Temperatura de corte de seguridade (°C)
#define GANANCIA_KP 1.0f         // Forza de resposta do controlador (P)
#define ALTURA_GRAFICO 64//48        // Altura do gráfico en píxeles
#define ANCHURA_GRAFICO 128      // Anchura do gráfico

// =============================================================================
// DEFINICIÓN DOS PINES DO ESP32-C3
// =============================================================================
#define PIN_SDA_I2C 9
#define PIN_SCL_I2C 10
#define PIN_TERMISTOR 3   // Entrada analóxica do sensor
#define PIN_CALEFACTOR 8  // Saída PWM para o calefactor
#define PIN_COD_ENC_A 6   // Canal A do codificador
#define PIN_COD_ENC_B 7   // Canal B do codificador
#define PIN_COD_SW 5      // Botón do codificador

// =============================================================================
// CONSTANTES FIXAS DO SISTEMA
// =============================================================================
const int PASO_TEMP = 5;
const long ATRASO_ANTIRREbote = 50;
const long INTERVALO_ACTUALIZACION_PANT = 200;
const long INTERVALO_ACTUALIZACION_GRAF = 2500;

// Parámetros do termistor NTC (100kΩ)
const float RESISTENCIA_NOMINAL = 100000.0f;
const float RESISTENCIA_DIVISOR = 32500.0f;
const float BETA_TERMISTOR = 3950.0f;
const float TEMP_NOMINAL = 25.0f;
const float TENSAO_ALIMENTACION = 3.3f;
const float ADC_MAXIMO = 4095.0f;

// =============================================================================
// DECLARACIÓN DO LOGO (definido ao final)
// =============================================================================
extern const unsigned char logo_XDeSIG_128x120[];

// =============================================================================
// VARIABLES GLOBAIS
// =============================================================================
float gananciaKp = GANANCIA_KP;
int temperaturaObxectivo = 230;
float puntoAxuste = temperaturaObxectivo;
float temperaturaActual = 0.0f;
int valorPWM = 0;

bool calefactorActivo = false;
bool controladorActivo = false;

enum EstadoControl { TEMPERATURA_BLOQUEADA,
                     TEMPERATURA_AXUSTE };
EstadoControl estadoActual = TEMPERATURA_AXUSTE;

Adafruit_SH1107 pantalla = Adafruit_SH1107(128, 128, &Wire, -1, 400000);
Encoder codificador(PIN_COD_ENC_A, PIN_COD_ENC_B);

long valorAnteriorCodificador = 0;
unsigned long ultimoPulsoBoton = 0;
bool estadoAnteriorBoton = HIGH;
unsigned long ultimaActualizacionPantalla = 0;
unsigned long ultimaActualizacionGrafico = 0;

float historicoTemperatura[ANCHURA_GRAFICO];
int indiceGrafico = 0;
bool graficoInicializado = false;

// =============================================================================
// FUNCIÓNS
// =============================================================================

float obterTemperatura(int valorADC) {
  if (valorADC <= 0 || valorADC >= ADC_MAXIMO)
    return valorADC <= 0 ? 500.0f : -50.0f;

  float voltaxeSaida = (float)valorADC * (TENSAO_ALIMENTACION / ADC_MAXIMO);
  float resistenciaTermistor = RESISTENCIA_DIVISOR * (voltaxeSaida / (TENSAO_ALIMENTACION - voltaxeSaida));

  float steinhart = log(resistenciaTermistor / RESISTENCIA_NOMINAL) / BETA_TERMISTOR;
  steinhart += 1.0f / (TEMP_NOMINAL + 273.15f);
  steinhart = 1.0f / steinhart - 273.15f;
  return steinhart;
}
// Pantalla de erro
void amosarPantallaErro() {
  pantalla.clearDisplay();
  pantalla.setTextSize(2);
  pantalla.setCursor(20, 20);
  pantalla.print("ERRO de");
  pantalla.setCursor(25, 40);
  pantalla.print("SENSOR!");

  pantalla.setTextSize(1);
  pantalla.setCursor(25, 70);
  pantalla.print("Comproba o");
  pantalla.setCursor(25, 80);
  pantalla.print("termistor.");
  pantalla.display();
}

void actualizarTemperaturaObxectivo(int variacion) {
  temperaturaObxectivo += variacion;
  temperaturaObxectivo = constrain(temperaturaObxectivo, TEMP_MINIMA, TEMP_MAXIMA);
  puntoAxuste = temperaturaObxectivo;
  Serial.print("Temperatura Obxectivo: ");
  Serial.println(temperaturaObxectivo);
}

void xestionarCodificador() {
  long valorActual = codificador.read();
  long variacion = valorActual - valorAnteriorCodificador;

  if (variacion != 0) {
    if (variacion > 0) {
      actualizarTemperaturaObxectivo(PASO_TEMP);
    } else {
      actualizarTemperaturaObxectivo(-PASO_TEMP);
    }
    valorAnteriorCodificador = valorActual;
  }
}

void xestionarBoton() {
  bool estadoActualBoton = digitalRead(PIN_COD_SW);
  unsigned long tempoActual = millis();

  if (estadoActualBoton == LOW && estadoAnteriorBoton == HIGH) {
    if (tempoActual - ultimoPulsoBoton > ATRASO_ANTIRREbote) {
      estadoActual = (estadoActual == TEMPERATURA_AXUSTE) ? TEMPERATURA_BLOQUEADA : TEMPERATURA_AXUSTE;
      controladorActivo = (estadoActual == TEMPERATURA_BLOQUEADA);
      Serial.println(estadoActual == TEMPERATURA_BLOQUEADA ? ">>> ESTADO: BLOQUEADO (CONTROL AUTOMÁTICO)" : ">>> ESTADO: AXUSTE (CONTROL MANUAL)");
      if (estadoActual == TEMPERATURA_AXUSTE) {
        valorAnteriorCodificador = codificador.read();
      }
      ultimoPulsoBoton = tempoActual;
    }
  }
  estadoAnteriorBoton = estadoActualBoton;
}

// Actualiza a pantalla OLED con toda a información
void actualizarPantalla() {
  pantalla.clearDisplay();

  // Título e versión
  pantalla.setTextSize(1);
  pantalla.setCursor(0, 0);
  pantalla.print("Contr.Pl.Quece ");
  pantalla.setCursor(128 - (strlen(VERSIÓN_SOFTWARE) * 6), 0);
  pantalla.print(VERSIÓN_SOFTWARE);

  // Temperatura actual (grande) + estado do calefactor
  pantalla.setTextSize(4);
  pantalla.setCursor(5, 12);
  pantalla.print((int)temperaturaActual);
  pantalla.setTextSize(1);

  // Unidade 'C'
  int lonxTextoTemp = String((int)temperaturaActual).length();
  int posX_C = 5 + (lonxTextoTemp * 24);
  pantalla.setCursor(posX_C, 15);
  pantalla.print("C");

  // Estado do calefactor (ON/OFF) á dereita
  int posX_estado = posX_C + 15;  // 6 píxeles despois do "C"
  pantalla.setTextSize(2);
  pantalla.setCursor(posX_estado, 22);
  int porcentaxe = (int)(valorPWM * 100 / 255);
  pantalla.print(porcentaxe);
  pantalla.print("%");


  // Liña separadora
  pantalla.drawLine(0, 44, 127, 44, SH110X_WHITE);

  // Temperatura obxectivo
  pantalla.setTextSize(2);
  pantalla.setCursor(0, 50);
  pantalla.print("Obx");
  if (estadoActual == TEMPERATURA_AXUSTE) {
    pantalla.setTextColor(SH110X_BLACK, SH110X_WHITE);
  }
  pantalla.setCursor(40, 50);
  pantalla.print(temperaturaObxectivo);
  pantalla.setTextSize(1);
  pantalla.print("c");
  pantalla.setCursor(90, 50);
  if (estadoActual == TEMPERATURA_AXUSTE) {
    pantalla.setTextColor(SH110X_WHITE, SH110X_BLACK);
    pantalla.setTextSize(2);
    pantalla.print("OFF");
  } else {
    pantalla.setTextSize(2);
    pantalla.print(" ON");
  }


  // Debuxa o gráfico de temperatura na parte inferior
  if (graficoInicializado) {
    const int desprazamentoY = 128 - ALTURA_GRAFICO;
    pantalla.fillRect(0, desprazamentoY, ANCHURA_GRAFICO, ALTURA_GRAFICO, SH110X_BLACK);

    const float tempMin = 0.0f;
    const float tempMax = 400.0f;
    const float rangoTemp = tempMax - tempMin;

    // Debuxa a curva de temperatura actual
    for (int x = 0; x < ANCHURA_GRAFICO; x++) {
      int indiceBuffer = (indiceGrafico + x) % ANCHURA_GRAFICO;
      float temp = historicoTemperatura[indiceBuffer];
      if (temp < tempMin) temp = tempMin;
      if (temp > tempMax) temp = tempMax;

      int y = desprazamentoY + (int)(ALTURA_GRAFICO - (temp - tempMin) * ALTURA_GRAFICO / rangoTemp);
      pantalla.drawPixel(x, y, SH110X_WHITE);
    }

    // Debuxa a liña do obxectivo con puntos separados (máis visible)
    if (temperaturaObxectivo >= tempMin && temperaturaObxectivo <= tempMax) {
      int yObxectivo = desprazamentoY + (int)(ALTURA_GRAFICO - (temperaturaObxectivo - tempMin) * ALTURA_GRAFICO / rangoTemp);
      for (int x = 0; x < ANCHURA_GRAFICO; x += 4) {
        pantalla.drawPixel(x, yObxectivo, SH110X_WHITE);
        pantalla.drawPixel(x + 1, yObxectivo, SH110X_WHITE);
      }
    }
  }

  pantalla.display();  // Mostra a pantalla (actualiza)
}
// =============================================================================
// SETUP
// =============================================================================
void setup() {
  Serial.begin(115200);

  Wire.begin(PIN_SDA_I2C, PIN_SCL_I2C);
  pantalla.begin(0x3C, true);
  pantalla.setRotation(3);
  pantalla.setTextColor(SH110X_WHITE);

  // Amosa o logo de XDeSIG durante 2 segundos
  pantalla.clearDisplay();
  pantalla.drawBitmap(0, 4, logo_XDeSIG_128x120, 128, 120, SH110X_WHITE);
  pantalla.display();
  delay(2000);

  pantalla.clearDisplay();
  pantalla.display();

  pinMode(PIN_COD_SW, INPUT_PULLUP);
  if (!ledcAttach(PIN_CALEFACTOR, 5000, 8)) {
    Serial.println("ERRO: Non se puido configurar o PWM!");
  }

  analogReadResolution(12);
  analogSetAttenuation(ADC_11db);

  valorAnteriorCodificador = codificador.read();
  Serial.println("Sistema v2.3.1 - XDeSIG");
}

// =============================================================================
// LOOP
// =============================================================================
void loop() {
  unsigned long tempoActual = millis();

  xestionarBoton();
  if (estadoActual == TEMPERATURA_AXUSTE) {
    xestionarCodificador();
  }

  int totalAdc = 0;
  for (int i = 0; i < 10; i++) {
    totalAdc += analogRead(PIN_TERMISTOR);
  }
  temperaturaActual = obterTemperatura(totalAdc / 10);

  // --- DETECCIÓN DE ERRO DO SENSOR ---
  if (temperaturaActual <= -49.0f) {
    valorPWM = 0;
    calefactorActivo = false;
    controladorActivo = false;
    estadoActual = TEMPERATURA_AXUSTE;
    ledcWrite(PIN_CALEFACTOR, 0);  // Apaga o triac inmediatamente
    amosarPantallaErro();
    delay(1000);
    return;
  }

  // CORTE DE EMERXENCIA
  if (temperaturaActual > CORTE_EMERXENCIA) {
    valorPWM = 0;
    controladorActivo = false;
    estadoActual = TEMPERATURA_AXUSTE;
    Serial.println("!!! CORTE DE EMERXENCIA: T > " + String(CORTE_EMERXENCIA) + "°C !!!");
  }

  // CONTROLADOR P SIMPLE
  if (controladorActivo) {
    float erro = puntoAxuste - temperaturaActual;
    valorPWM = (int)(gananciaKp * erro);
    if (valorPWM < 0) valorPWM = 0;
    if (valorPWM > PWM_MAX_SAIDA) valorPWM = PWM_MAX_SAIDA;
    calefactorActivo = (valorPWM > 0);
  } else {
    valorPWM = 0;
    calefactorActivo = false;
  }

  ledcWrite(PIN_CALEFACTOR, (uint32_t)valorPWM);

  Serial.print("T: ");
  Serial.print(temperaturaActual, 1);
  Serial.print("C | Obx: ");
  Serial.print(temperaturaObxectivo);
  Serial.print("C | PWM: ");
  Serial.println(valorPWM);

  if (tempoActual - ultimaActualizacionPantalla >= INTERVALO_ACTUALIZACION_PANT) {
    actualizarPantalla();
    ultimaActualizacionPantalla = tempoActual;
  }

  if (tempoActual - ultimaActualizacionGrafico >= INTERVALO_ACTUALIZACION_GRAF) {
    historicoTemperatura[indiceGrafico] = temperaturaActual;
    indiceGrafico = (indiceGrafico + 1) % ANCHURA_GRAFICO;
    graficoInicializado = true;
    ultimaActualizacionGrafico = tempoActual;
  }
}

// =============================================================================
// LOGO XDeSIG - 128x120 px
// =============================================================================
const unsigned char PROGMEM logo_XDeSIG_128x120[] = {
  // 'Xdesig_128', 128x120px
  0x00, 0x03, 0xff, 0xff, 0x00, 0x00, 0x00, 0x00, 0x00, 0x00, 0x00, 0x00, 0x7f, 0xff, 0x80, 0x00,
  0x00, 0x01, 0xff, 0xff, 0x80, 0x00, 0x00, 0x00, 0x00, 0x00, 0x00, 0x00, 0xff, 0xff, 0x80, 0x00,
  0x00, 0x01, 0xff, 0xff, 0xc0, 0x00, 0x00, 0x00, 0x00, 0x00, 0x00, 0x00, 0xff, 0xff, 0x00, 0x00,
  0x00, 0x00, 0xff, 0xff, 0xc0, 0x00, 0x00, 0x00, 0x00, 0x00, 0x00, 0x01, 0xff, 0xfe, 0x00, 0x00,
  0x00, 0x00, 0x7f, 0xff, 0xe0, 0x00, 0x00, 0x00, 0x00, 0x00, 0x00, 0x03, 0xff, 0xfe, 0x00, 0x00,
  0x00, 0x00, 0x3f, 0xff, 0xf0, 0x00, 0x00, 0x00, 0x00, 0x00, 0x00, 0x07, 0xff, 0xfc, 0x00, 0x00,
  0x00, 0x00, 0x3f, 0xff, 0xf8, 0x00, 0x00, 0x00, 0x00, 0x00, 0x00, 0x07, 0xff, 0xf8, 0x00, 0x00,
  0x00, 0x00, 0x1f, 0xff, 0xf8, 0x00, 0x00, 0x00, 0x00, 0x00, 0x00, 0x0f, 0xff, 0xf0, 0x00, 0x00,
  0x00, 0x00, 0x0f, 0xff, 0xfc, 0x00, 0x00, 0x00, 0x00, 0x00, 0x00, 0x1f, 0xff, 0xf0, 0x00, 0x00,
  0x00, 0x00, 0x0f, 0xff, 0xfe, 0x00, 0x00, 0x00, 0x00, 0x00, 0x00, 0x3f, 0xff, 0xe0, 0x00, 0x00,
  0x00, 0x00, 0x07, 0xff, 0xfe, 0x00, 0x00, 0x00, 0x00, 0x00, 0x00, 0x3f, 0xff, 0xc0, 0x00, 0x00,
  0x00, 0x00, 0x03, 0xff, 0xff, 0x00, 0x00, 0x00, 0x00, 0x00, 0x00, 0x7f, 0xff, 0xc0, 0x00, 0x00,
  0x00, 0x00, 0x01, 0xff, 0xff, 0x80, 0x00, 0x00, 0x00, 0x00, 0x00, 0xff, 0xff, 0x80, 0x00, 0x00,
  0x00, 0x00, 0x01, 0xff, 0xff, 0x80, 0x00, 0x00, 0x00, 0x00, 0x01, 0xff, 0xff, 0x00, 0x00, 0x00,
  0x00, 0x00, 0x00, 0xff, 0xff, 0xc0, 0x00, 0x00, 0x00, 0x00, 0x01, 0xff, 0xfe, 0x00, 0x00, 0x00,
  0x00, 0x00, 0x00, 0x7f, 0xff, 0xe0, 0x00, 0x00, 0x00, 0x00, 0x03, 0xff, 0xfe, 0x00, 0x00, 0x00,
  0x00, 0x00, 0x00, 0x7f, 0xff, 0xf0, 0x00, 0x00, 0x00, 0x00, 0x07, 0xff, 0xfc, 0x00, 0x00, 0x00,
  0x00, 0x00, 0x00, 0x3f, 0xff, 0xf0, 0x00, 0x00, 0x00, 0x00, 0x0f, 0xe0, 0x00, 0x00, 0x00, 0x00,
  0x00, 0x00, 0x00, 0x00, 0xff, 0xf8, 0x00, 0x00, 0x00, 0x00, 0x1e, 0x00, 0x00, 0x00, 0x00, 0x00,
  0x00, 0x00, 0x00, 0x00, 0x00, 0xfc, 0x00, 0x00, 0x00, 0x00, 0x10, 0x00, 0x00, 0x00, 0x00, 0x00,
  0x00, 0x00, 0x00, 0x00, 0x00, 0x1c, 0x00, 0x00, 0x00, 0x00, 0x00, 0x3f, 0xff, 0xe0, 0x00, 0x00,
  0xff, 0xff, 0xff, 0xff, 0xe0, 0x06, 0x00, 0x00, 0x00, 0x00, 0x01, 0xff, 0xff, 0xfe, 0x00, 0x00,
  0xff, 0xff, 0xff, 0xff, 0xff, 0x01, 0x00, 0x00, 0x00, 0x00, 0x0f, 0xff, 0xff, 0xff, 0x80, 0x00,
  0xff, 0xff, 0xff, 0xff, 0xff, 0xe0, 0x00, 0x00, 0x00, 0x00, 0x3f, 0xff, 0xff, 0xff, 0xe0, 0x00,
  0xff, 0xff, 0xff, 0xff, 0xff, 0xf8, 0x00, 0x00, 0x00, 0x00, 0x7f, 0xff, 0xff, 0xff, 0xf8, 0x00,
  0xff, 0xff, 0xff, 0xff, 0xff, 0xfc, 0x00, 0x00, 0x00, 0x01, 0xff, 0xff, 0xff, 0xff, 0xfc, 0x00,
  0xff, 0xff, 0xff, 0xff, 0xff, 0xff, 0x00, 0x00, 0x00, 0x03, 0xff, 0xff, 0xff, 0xff, 0xfe, 0x00,
  0xff, 0xff, 0xff, 0xff, 0xff, 0xff, 0x80, 0x00, 0x00, 0x07, 0xff, 0xff, 0xff, 0xff, 0xff, 0x00,
  0xff, 0xff, 0xff, 0xff, 0xff, 0xff, 0xc0, 0x00, 0x00, 0x07, 0xff, 0xe0, 0x00, 0x3f, 0xff, 0x80,
  0xff, 0xc0, 0x00, 0x00, 0x7f, 0xff, 0xe0, 0x00, 0x00, 0x0f, 0xff, 0x00, 0x00, 0x07, 0xff, 0xc0,
  0xff, 0x80, 0x00, 0x00, 0x07, 0xff, 0xf0, 0x00, 0x00, 0x1f, 0xfc, 0x00, 0x00, 0x01, 0xff, 0xc0,
  0xff, 0x80, 0x00, 0x00, 0x00, 0xff, 0xf8, 0x00, 0x00, 0x1f, 0xf8, 0x00, 0x00, 0x00, 0xff, 0xe0,
  0xff, 0x80, 0x00, 0x00, 0x00, 0x7f, 0xf8, 0x00, 0x00, 0x3f, 0xf0, 0x00, 0x00, 0x00, 0x7f, 0xe0,
  0xff, 0x80, 0x00, 0x00, 0x00, 0x3f, 0xfc, 0x00, 0x00, 0x3f, 0xe0, 0x00, 0x00, 0x00, 0x3f, 0xf0,
  0xff, 0x80, 0x00, 0x00, 0x00, 0x1f, 0xfe, 0x00, 0x00, 0x3f, 0xe0, 0x00, 0x00, 0x00, 0x3f, 0xf0,
  0xff, 0x80, 0x00, 0x00, 0x00, 0x0f, 0xfe, 0x00, 0x00, 0x7f, 0xc0, 0x00, 0x00, 0x00, 0x1f, 0xf0,
  0xff, 0x80, 0x00, 0x00, 0x00, 0x07, 0xff, 0x00, 0x02, 0x7f, 0xc0, 0x00, 0x00, 0x00, 0x1f, 0xf8,
  0xff, 0x80, 0x00, 0x00, 0x00, 0x03, 0xff, 0x00, 0x04, 0x7f, 0xc0, 0x00, 0x00, 0x00, 0x0f, 0xf8,
  0xff, 0x80, 0x00, 0x00, 0x00, 0x03, 0xff, 0x80, 0x04, 0x7f, 0xc0, 0x00, 0x00, 0x00, 0x0f, 0xf8,
  0xff, 0x80, 0x00, 0x00, 0x00, 0x01, 0xff, 0x80, 0x0c, 0x7f, 0xc0, 0x00, 0x00, 0x00, 0x0f, 0xf8,
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
};

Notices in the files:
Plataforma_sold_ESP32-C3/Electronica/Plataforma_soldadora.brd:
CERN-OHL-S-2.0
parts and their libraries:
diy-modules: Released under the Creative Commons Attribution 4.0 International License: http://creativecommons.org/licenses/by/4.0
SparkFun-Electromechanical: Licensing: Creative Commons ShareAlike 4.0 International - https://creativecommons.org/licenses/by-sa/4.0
